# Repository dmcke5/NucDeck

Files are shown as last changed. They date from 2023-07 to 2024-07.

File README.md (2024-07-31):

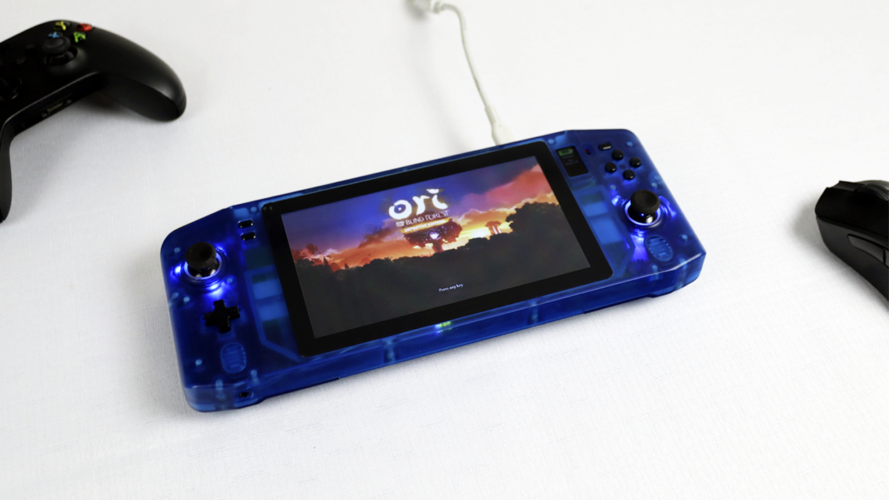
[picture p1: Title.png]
NucDeck


# NucDeck
The Open Source DIY Handheld Gaming PC!

Refer to "NucDeck Assembly Instructions.PDF" for mechanical assembly details. Information for the electronics will be added once the controller PCB's are complete.

There are two different versions of the housing, Standard and NoRGB. The NoRGB version has had
the RGB joystick surrounds removed to simplify printing. If you choose the NoRGB version you can leave all of the 
associated components off the PCB's to save on cost.

There are two different versions of the buttons, membrane and clicky. The Membrane buttons are shorter and are
designed to be used with silicone membranes. I've included files for molds to make the membranes. If you have a resin printer
I encourage you to give this a try as it improves the feel of the buttons dramatically. FDM printers will struggle to produce the accuracy required to make these parts. The clicky version is slightly taller and can be used without the membranes.

Total Cost of parts approximately: $311 USD

This is based on PCBway's pricing for the PCB's and is not including a NUC or any shipping charges. I've probably missed counting something so I would budget for a little more!

Here's a breakdown of the costs:
- Digikey parts: $55 USD
- PCB's (Set of 5 due to MOQ): $204 USD
- Aliexpress Parts: $52 USD

If you can organise a group of 5 people who want a set of PCB's, you will greatly reduce your total cost to build.

#### Project Status
- [x] 3D Files
- [x] Software: V1.0 ready for testing. Motion controls not yet implemented
- [x] PCBs: Complete

Watch the series on Youtube as I design, build and test parts of this project:
- [Episode 1](https://youtu.be/xVYYCx3Qt4Y)
- [Episode 2](https://youtu.be/nOXd3axX4fw)
- [Episode 3](https://youtu.be/yHMnScoKIOE)
- [Episode 4](https://youtu.be/rP_sMztufNs)
- [Episode 5](https://youtu.be/sQocfy4pwIQ)
- [Bonus Episode - Battery Life Testing](https://youtu.be/6FQKwnMxRxI)
- [Episode 6](https://youtu.be/mfuAvgmuT2s)
- [Episode 7](https://youtu.be/nFNw7_WkteA)
- [Episode 8](https://youtu.be/YYRD0Zlga5s)
- [Episode 9](https://youtu.be/t9Rao_BeIeM)

I've found links for all of the parts on Aliexpress since its probably the cheapest option and will ship worldwide.

## Parts List

#### Display

Any 1024x600 50 Pin RGB Panel with overall dimensions no greater than 164.9x100x3.3mm.
This is the 700nit IPS panel I ended up using: https://www.aliexpress.com/item/1005005315348504.html

#### Display Driver

Pick the "PCB800812V1" option:
https://www.aliexpress.com/item/1005004252996145.html

#### USB Touch Controller

Pick option "USB Controller":
https://www.aliexpress.com/item/32976239800.html

#### Capacitive Touch Panel

This is the seller I used, but anyone selling for the same model tablet (Pritom K7) should do:
https://www.aliexpress.com/item/1005002490383977.html

#### Joysticks

Joysticks are an Alps RKJX21224001. Here's a cheap seller on aliexpress:
https://www.aliexpress.com/item/1005005264696228.html
Joystick caps are Xbox One compatible.

#### Batteries

4x 605080 3000mah Lithium cells. Here's a cheap supplier on Aliexpress:
https://www.aliexpress.com/item/32990176071.html

#### Info Screen

0.96" IPS 80x160 ST7735 TFT Display

You need the one these guys refer to as "Spliced Type".
https://www.aliexpress.com/item/1005001598020071.html

#### Threaded Inserts

Measurments are: Thread x OD x Length

17x M2x3.2x4

10x M3x5x5

2x M3x5x4

https://www.aliexpress.com/item/1005003582355741.html

#### Standoffs

10x M2x6mm Male to Female Standoffs
https://www.aliexpress.com/item/4001271908929.html

#### Trigger Springs

--NOTE-- Ignore the wire thickness in the Assembly Drawing, it is incorrect. I will fix it when I next need to make changes. Correct thickness listed here.
These guys have a lot of different options, they are pretty cheap so I'd grab a few different wire thicknesses
and test them out to see what you like. You need about 2mm ID on the coil section, so look for an ID of at least double the wire
thickness greater than 2mm. I found 0.4mm to feel a bit too thin, and 0.7mm is about the limit of the trigger supports so 0.5-0.6mm is probably the sweet spot.
https://www.aliexpress.com/item/1005004968066601.html

#### Trigger Magnets

You'll never need fridge magnets again!
https://www.aliexpress.com/item/1005003794726533.html

#### RGB Lights

You'll need both RGB LED's and WS2811 IC's if you're adding RGB to your controller PCB's.
These are the LED's I used. Any alternative in the same sized package should be fine too, just be cautious of
differing pin configurations.
https://www.aliexpress.com/item/1005003719602946.html

WS2811 IC's:
https://www.aliexpress.com/item/32844615804.html

#### Screws

Here's a list of the screws required for assembly. This list is also in the assembly instructions. SCHS is just a standard allen key head screw. CSK is a countersunk head screw. Most bolt suppliers should have these, otherwise ebay or aliexpress is your friend.

12x M3x6mm SHCS
2x M2x16 CSK
9x M2x5 CSK
14x M2x4 SHCS

#### 4s Cell Balancer
https://www.aliexpress.com/item/1005005827876691.html

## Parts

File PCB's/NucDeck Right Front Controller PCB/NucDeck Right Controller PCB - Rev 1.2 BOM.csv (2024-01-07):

All parts available from Digikey unless otherwise specified
Ref | Qnty | Value/Part Number | Footprint | Supplier
A1,B1,X1,Y1,MENU1 | 5 | EVQ-Q2B02W | SW_EVQ-Q2B02W
C1, C2, C3, C4 | 4 | 0.1uF | Capacitor 0603_1608Metric
D1, D2, D3 | 3 | LED_BRGK | LED_SMD:LED_T36K3BGR-05D000121U1930 | https://www.aliexpress.com/item/1005003719602946.html
Display_Power1 | 1 | 532617002 | MOLEX_532617002
J1 | 1 | 5052781033 | Molex Easy On Connector:Molex 5052781033
J2 | 1 | 2-1734592-2 | CONN22_2-1734592-2
J3 | 1 | 5051100892 | CON_5051100892_MOL
J4 | 1 | USB4125-GF-A-0190 | USB4125-GF-A-0190
POWER1 | 1 | TL3330AF130QG | SW_TL3330AF130QG
R1 | 1 | TL1105VF160Q | SW_TL1105VF160Q
R2, R3, R5, R6, R8, R10 | 6 | R33 | Resistor 0603_1608Metric
R4, R7, R9 | 3 | 100R | Resistor 0603_1608Metric
R11 | 1 | 15ohm | Resistor 0603_1608Metric
R12 | 1 | 10ohm | Resistor 0603_1608Metric
R13 | 1 | 49.9K | Resistor 0603_1608Metric
R14 | 1 | 5.1K | Resistor 0603_1608Metric
Right_Speaker1 | 1 | 532617002 | MOLEX_532617002
Toggle_Switch1 | 1 | SW_SPDT | NKK Slide Switch:NKK SS12SBP2
U1, U2, U3 | 3 | WS2811 | SOP-8_3.9x4.9mm_P1.27mm | https://www.aliexpress.com/item/32844615804.html
U4 | 1 | HUSB238 | DFN-10-1EP_3x3mm_P0.5mm_EP1.7x2.5mm | https://www.aliexpress.com/item/1005005555514096.html
U5 | 1 | FQD11P06TM | TO-252-3_ONS
U6 | 1 | BAT54XV2T1G | SOD-523_0P9X1P3_ONS
U7 | 1 | VO1400AEFTR | SO-4_VO_VIS

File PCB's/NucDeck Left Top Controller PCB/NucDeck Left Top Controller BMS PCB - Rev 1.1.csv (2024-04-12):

Qty | Reference(s) | Value
2 | C1, C2 | 47nF
1 | C3 | 4.7uF
9 | C4, C5, C6, C12, C13, C15, C16, C17, C18 | 10uF
7 | C7, C10, C11, C14, C21, C24, C31 | 0.1uF
1 | C8 | 1nF
1 | C9 | 2.2uF
2 | C19, C20 | 10uF
2 | C25, C26 | 1uF
1 | C27 | .47uF
1 | C28 | .1uF
1 | D1 | LED
1 | J1 | 527450697
1 | J2 | Molex 5052781033
1 | J3 | S5B-EH
1 | L1 | SPM6530T-2R2M
1 | R1 | 2.2K
1 | R2 | 27k
2 | R3, R13 | 100k
1 | R4 | 127k
1 | R5 | 2ohm
1 | R6 | 30.31K
1 | R7 | 5.24K
1 | R8 | 100ohm
1 | R12 | PCS2512DR0100ET
1 | R14 | 11.1k
1 | Thermistor | 103AT-5-1P-FT
1 | U1 | MAX17261METD+
1 | U2 | BQ25792RQMR
1 | U3 | DRV5053OAQDBZR
1 | U4 | SMBJ24CA
1 | U6 | NCP718xSN330

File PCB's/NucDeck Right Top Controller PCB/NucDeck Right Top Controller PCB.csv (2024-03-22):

All parts available from digikey unless otherwise specified
Qty | Reference(s) | Value | Footprint
6 | C1, C2, C3, C4, C5, C6 | 0.1uF | Capacitor 0603_1608Metric
1 | J1 | 527450697 | CON_527450697_MOL
1 | J2 | 2-1734592-2 | CONN22_2-1734592-2
1 | U1 | Pico | Raspberry Pi Pico
1 | U3 | DRV5053OAQDBZR | DBZ0003A_N

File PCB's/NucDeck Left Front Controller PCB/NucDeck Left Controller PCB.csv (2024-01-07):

All parts available from Digikey unless otherwise specified
Qty | Reference(s) | Value/Part Number | Footprint | Supplier
1 | C1 | 4.7uF | Capacitor 0603_1608Metric
8 | C2, C3, C6, C7, C8, C15, C16, C17 | 0.1uF | Capacitor 0603_1608Metric
2 | C4, C5 | 22pF | Capacitor 0603_1608Metric
3 | D1, D2, D3 | LED_BRGK | LED_T36K3BGR-05D000121U1930 | https://www.aliexpress.com/item/1005003719602946.html
6 | DN1, LEFT1, RIGHT1, Select1, Start1, UP1 | EVQ-Q2B02W | SW_EVQ-Q2B02W
1 | J1 | SJ-43516-SMT-TR | CUI_SJ-43516-SMT
2 | J2, J4 | 5052781033 | Molex 5052781033
1 | J3 | 532617002 | MOLEX_532617002
1 | L1 | TL1105VF160Q | SW_TL1105VF160Q
1 | R1 | 1K | Resistor 0603_1608Metric
3 | R2, R7, R10 | 100R | Resistor 0603_1608Metric
5 | R3, R4, R5, R6, R8 | R33 | Resistor 0603_1608Metric
1 | U1 | ATmega328P-A | TQFP-32_7x7mm_P0.8mm
3 | U2, U3, U4 | WS2811 | SOP-8_3.9x4.9mm_P1.27mm | https://www.aliexpress.com/item/32844615804.html
2 | Vol+1, Vol-1 | TL3330AF130QG | SW_TL3330AF130QG
1 | Y1 | 16 MHZ | Crystal_SMD_5032-4Pin_5.0x3.2mm

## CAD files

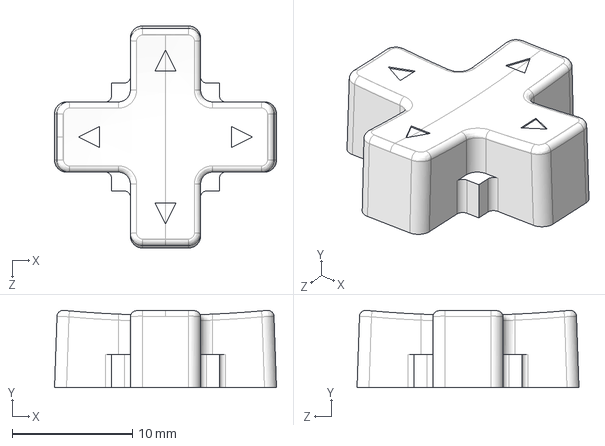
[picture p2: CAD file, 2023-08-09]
Buttons - STEP/Clicky Buttons - STEP/NUCDeck D-Pad - Clicky.STEP
18.5 x 6.42 x 18.5 mm

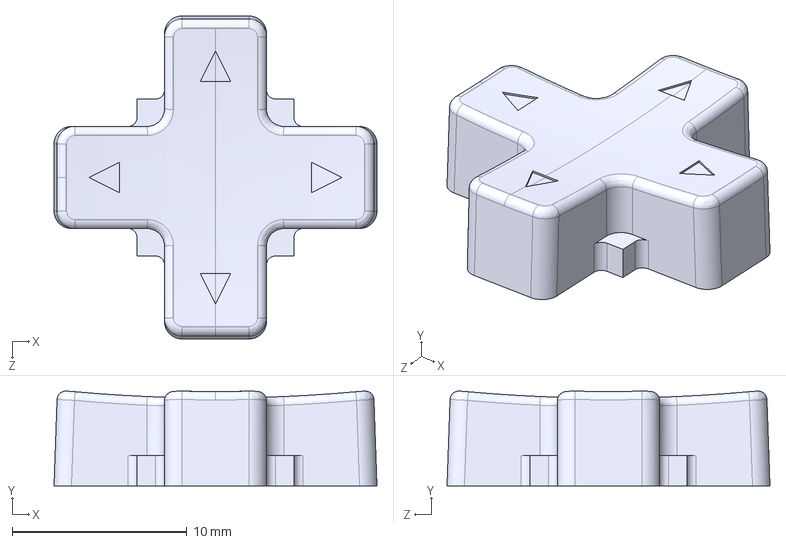
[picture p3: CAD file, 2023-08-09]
Buttons - STEP/Membrane Buttons - STEP/D-Pad - Standard.STEP
18.5 x 5.43 x 18.5 mm

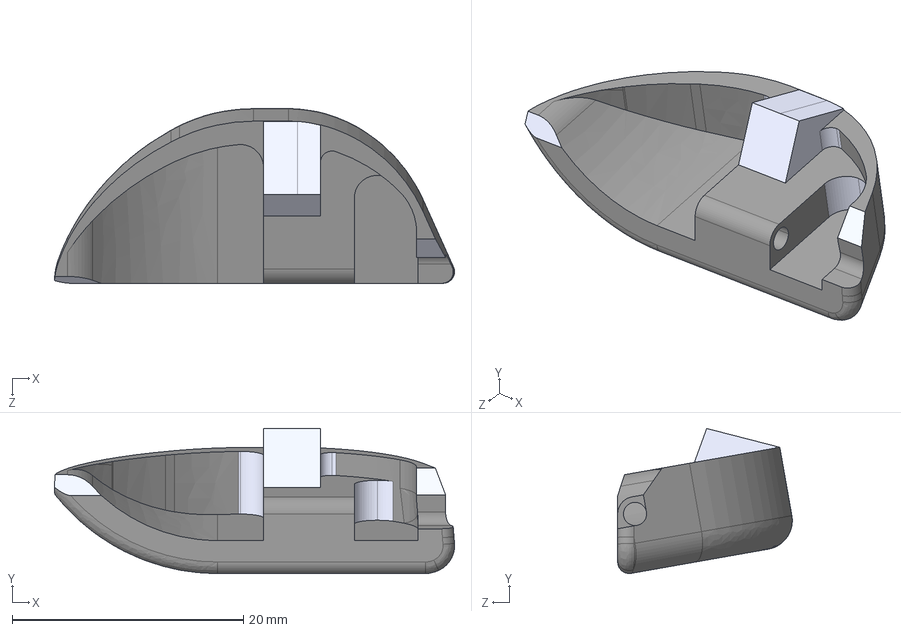
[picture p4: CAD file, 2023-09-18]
Buttons - STEP/Trigger Button Right.STEP
34.6 x 12.5 x 15.1 mm

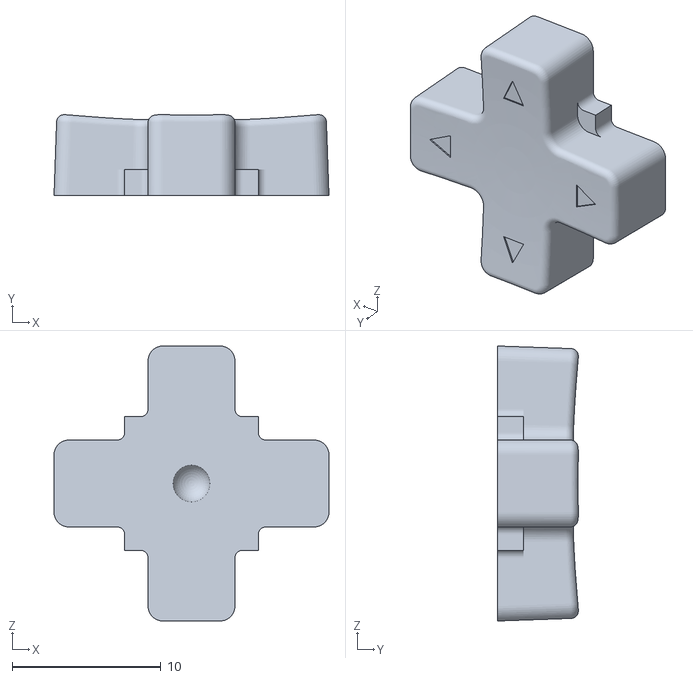
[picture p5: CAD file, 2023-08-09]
Buttons - STL/Membrane Buttons - STL/NUCDeck D-Pad - Standard.STL
18.5 x 5.43 x 18.5

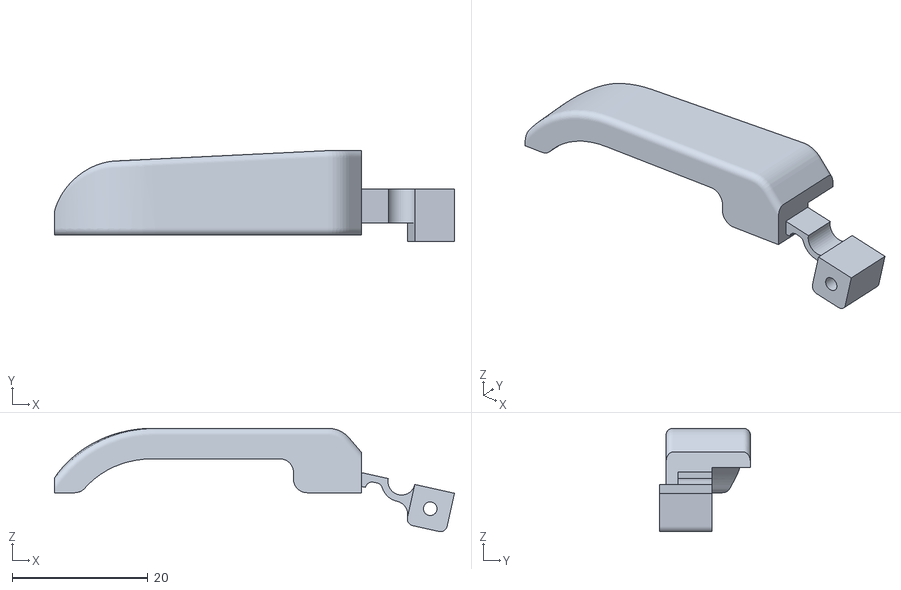
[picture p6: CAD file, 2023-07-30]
Buttons - STL/Right Shoulder Button - Printable Version.STL
59.0 x 13.4 x 15.2

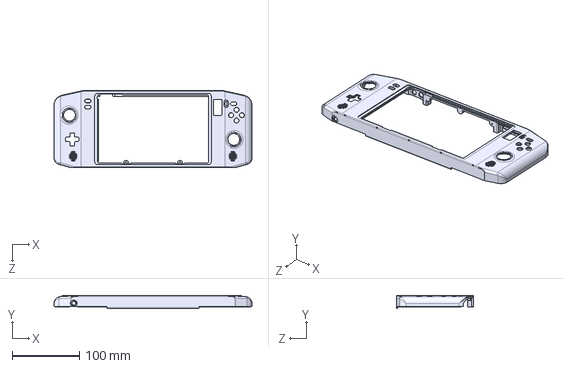
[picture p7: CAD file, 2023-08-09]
Housing - STEP/Housing Front - No RGB.STEP
294.0 x 19.0 x 115.0 mm

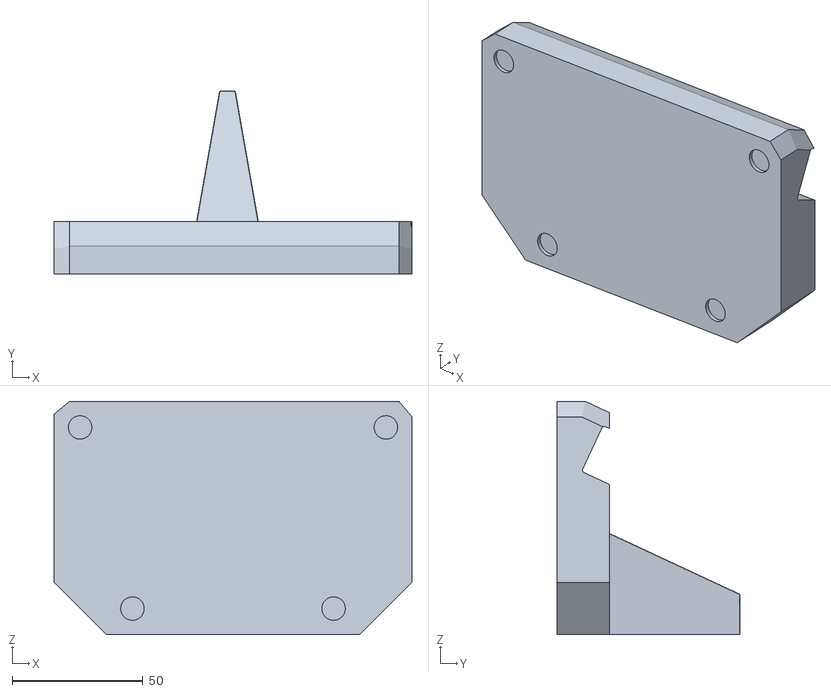
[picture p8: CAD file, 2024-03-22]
NucDeck Desktop Stand.STL
137.0 x 70.0 x 89.3

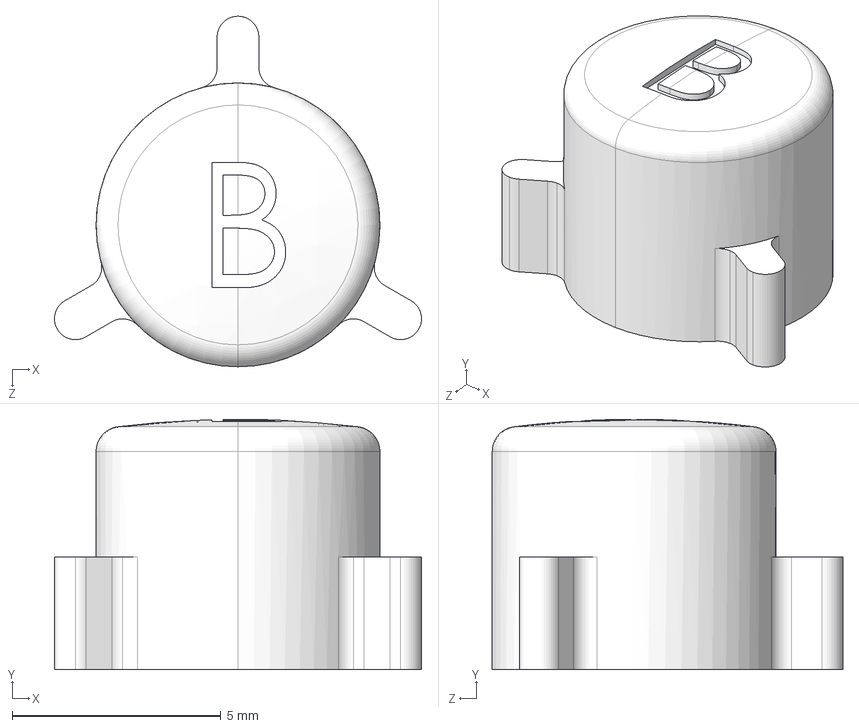
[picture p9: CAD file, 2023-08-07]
Buttons - STEP/Clicky Buttons - STEP/Action Button B - Clicky.STEP
8.79 x 6.00 x 8.40 mm

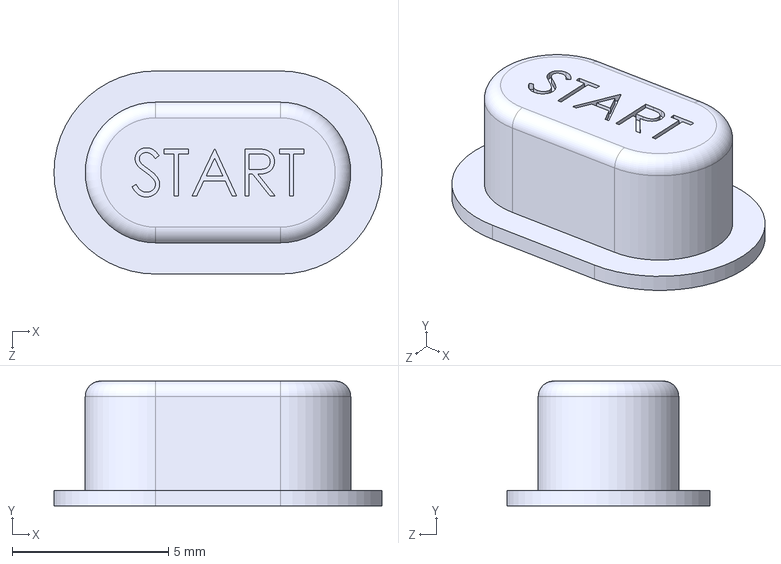
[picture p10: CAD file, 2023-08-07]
Buttons - STEP/Membrane Buttons - STEP/Start Button - Standard.STEP
10.5 x 4.00 x 6.50 mm

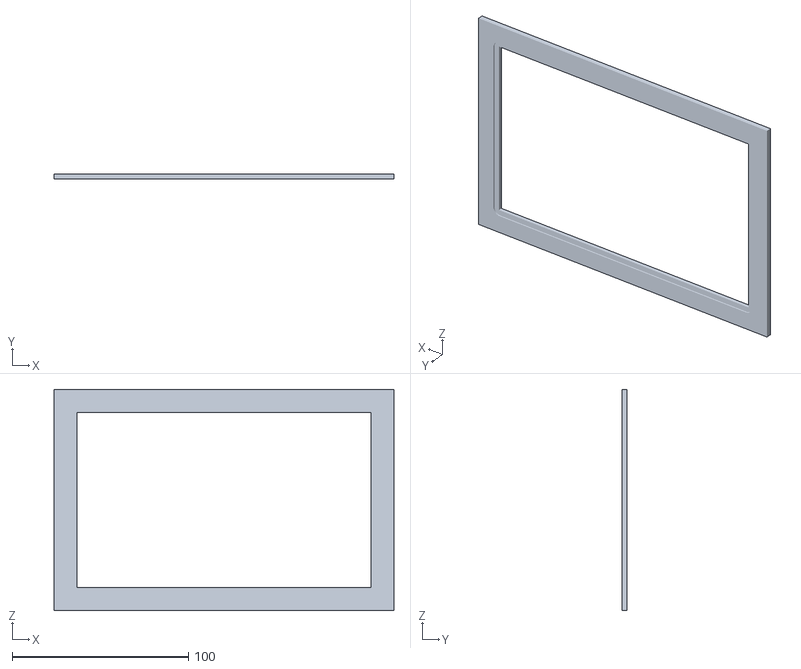
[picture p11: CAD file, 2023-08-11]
TouchScreen Scale Test.STL
193.0 x 3.00 x 125.6

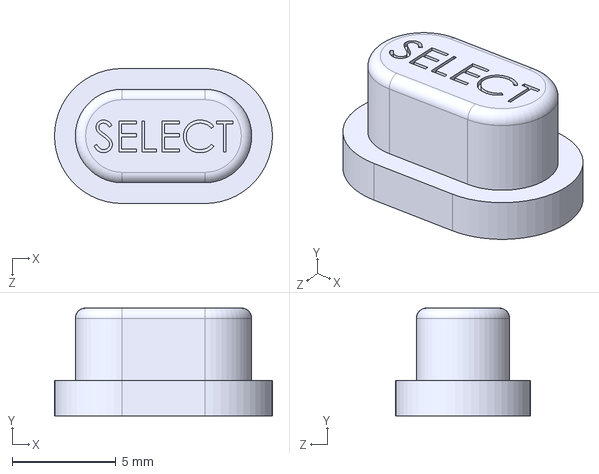
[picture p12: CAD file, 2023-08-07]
Buttons - STEP/Clicky Buttons - STEP/Select Button - Clicky.STEP
10.5 x 5.20 x 6.50 mm

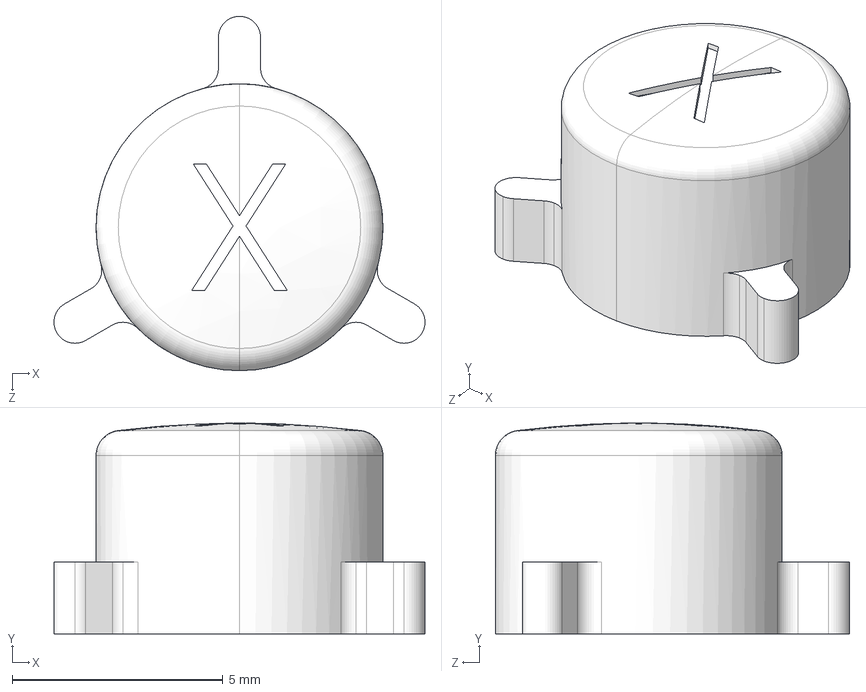
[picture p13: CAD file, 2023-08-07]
Buttons - STEP/Membrane Buttons - STEP/Action Button X - Standard.STEP
8.79 x 5.00 x 8.40 mm

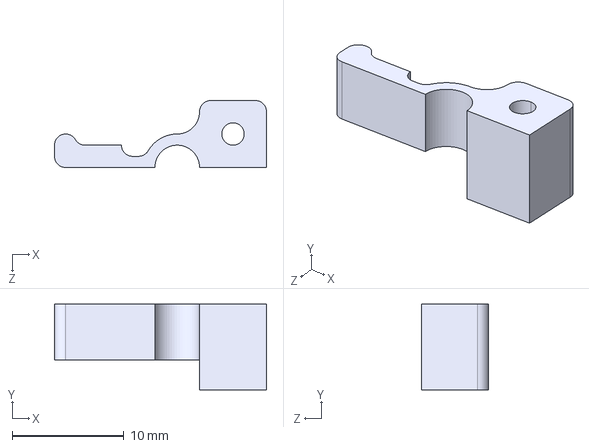
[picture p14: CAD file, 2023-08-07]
Buttons - STEP/Shoulder Spring - Right.STEP
19.0 x 7.70 x 6.00 mm

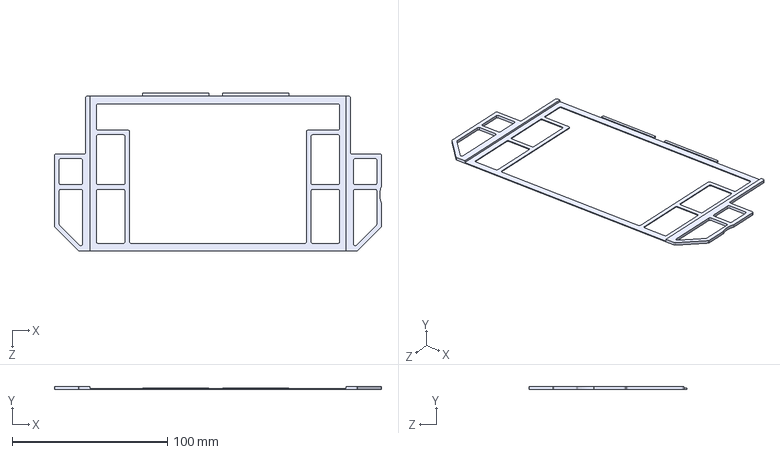
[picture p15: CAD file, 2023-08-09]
Housing - STEP/LCD Retainer.STEP
210.9 x 1.90 x 102.0 mm

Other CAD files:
Buttons - STEP/Trigger Button Left.STEP
Buttons - STL/Left Shoulder Button - Printable Version.STL
Housing - STEP/Housing Front.STEP
Buttons - STEP/Clicky Buttons - STEP/Start Button - Clicky.STEP
Buttons - STEP/+ Volume Button.STEP
Buttons - STEP/- Volume Button.STEP
Buttons - STEP/Clicky Buttons - STEP/Action Button A - Clicky.STEP
Buttons - STEP/Clicky Buttons - STEP/Action Button X - Clicky.STEP
Buttons - STEP/Clicky Buttons - STEP/Action Button Y - Clicky.STEP
Buttons - STEP/Clicky Buttons - STEP/Menu Button - Clicky.STEP
Buttons - STEP/Controller Mode Toggle.STEP
Buttons - STEP/Membrane Buttons - STEP/Action Button A - Standard.STEP
Buttons - STEP/Membrane Buttons - STEP/Action Button B - Standard.STEP
Buttons - STEP/Membrane Buttons - STEP/Action Button Y - Standard.STEP
Buttons - STEP/Membrane Buttons - STEP/Menu Button - Standard.STEP
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

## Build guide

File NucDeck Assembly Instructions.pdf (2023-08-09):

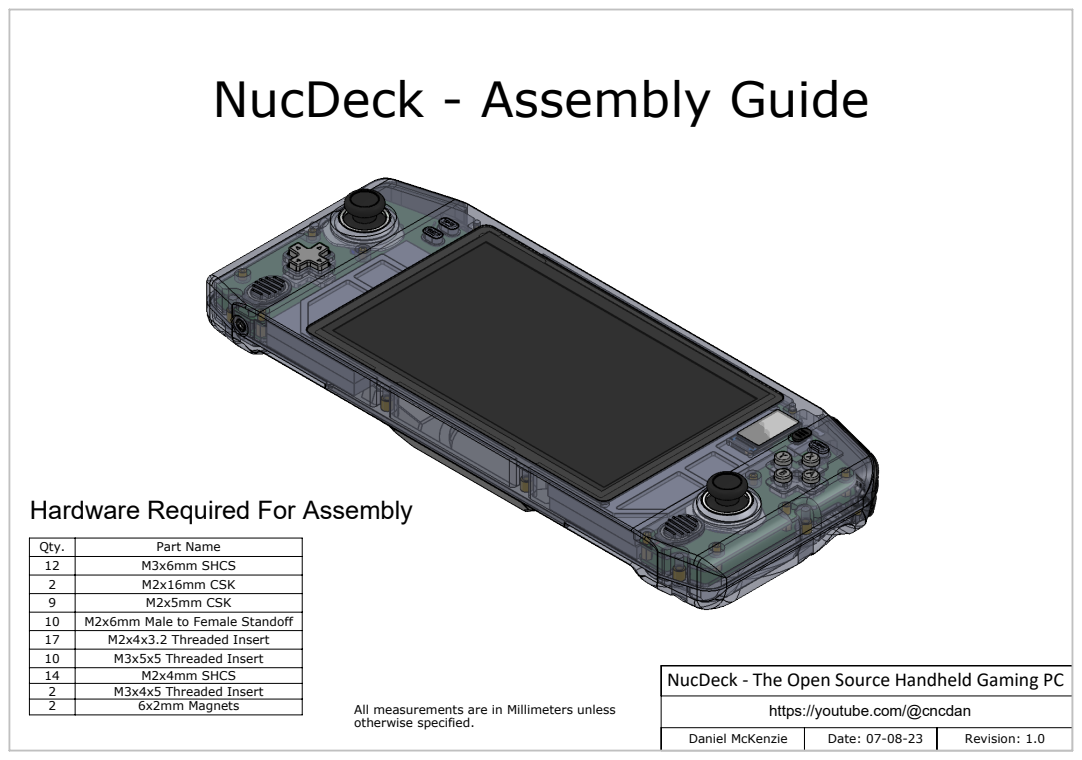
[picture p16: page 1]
M2x4mm SHCS; Daniel McKenzie; Date: 07-08-23; Revision: 1.0

NucDeck - Assembly Guide

Hardware Required For Assembly

Qty. | Part Name
12 | M3x6mm SHCS
2 | M2x16mm CSK
9 | M2x5mm CSK
10 | M2x6mm Male to Female Standoff
17 | M2x4x3.2 Threaded Insert
10 | M3x5x5 Threaded Insert

NucDeck - The Open Source Handheld Gaming PC

2 | M3x4x5 Threaded Insert
2 | 6x2mm Magnets

All measurements are in Millimeters unless
otherwise specified.

https://youtube.com/@cncdan

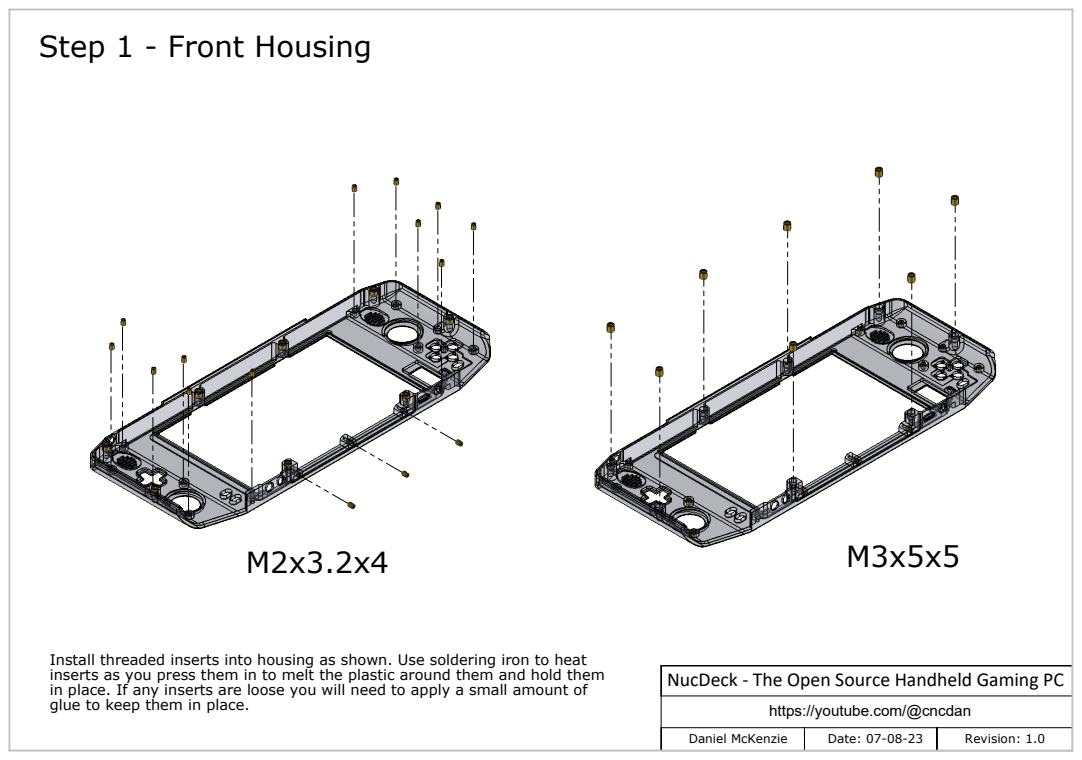
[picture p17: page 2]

Step 1 - Front Housing

Install threaded inserts into housing as shown. Use soldering iron to heat
inserts as you press them in to melt the plastic around them and hold them
in place. If any inserts are loose you will need to apply a small amount of
glue to keep them in place.

NucDeck - The Open Source Handheld Gaming PC

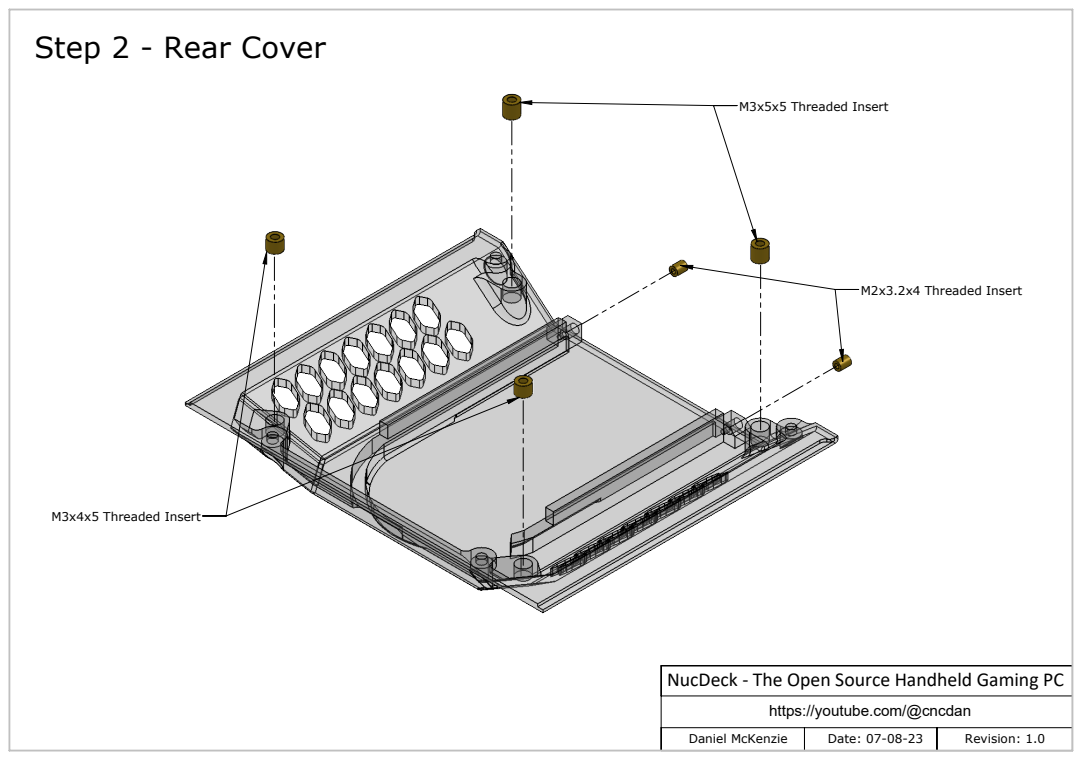
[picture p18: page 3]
M3x5x5 Threaded Insert; M3x4x5 Threaded Insert; M2x3.2x4 Threaded Insert

Step 2 - Rear Cover

NucDeck - The Open Source Handheld Gaming PC

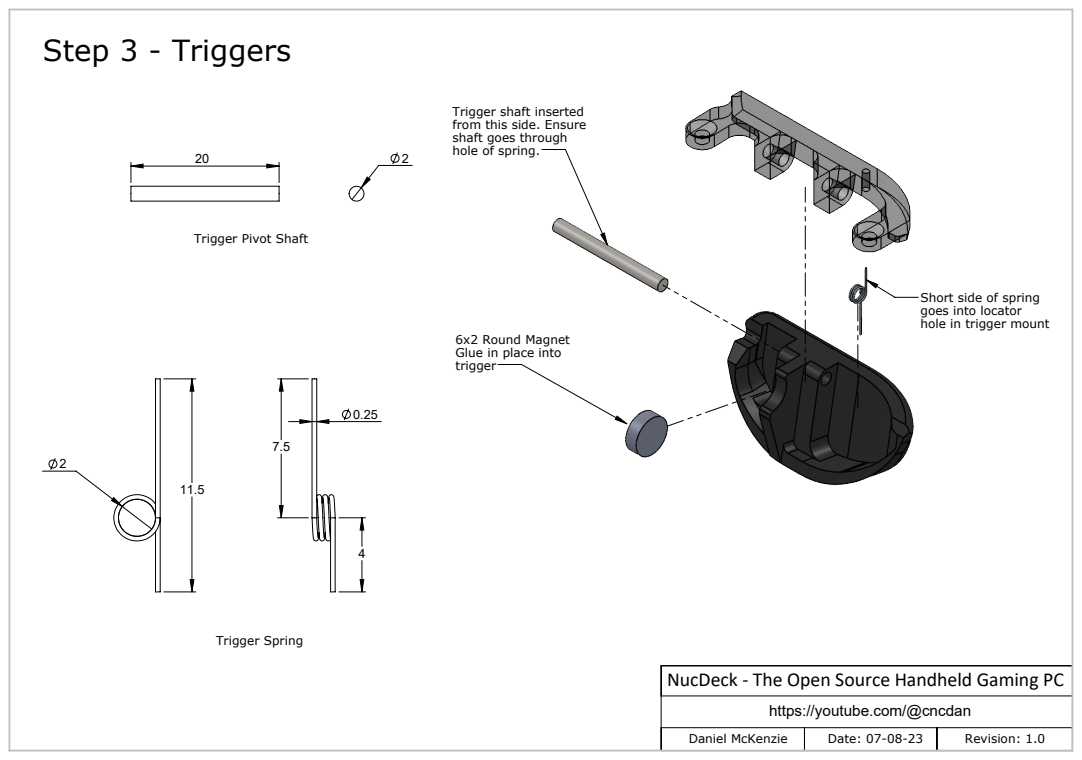
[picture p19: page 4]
Step 3 - Triggers; Trigger Spring

Trigger shaft inserted
from this side. Ensure
shaft goes through
hole of spring.

Trigger Pivot Shaft

Short side of spring
goes into locator
hole in trigger mount

6x2 Round Magnet
Glue in place into
trigger

NucDeck - The Open Source Handheld Gaming PC

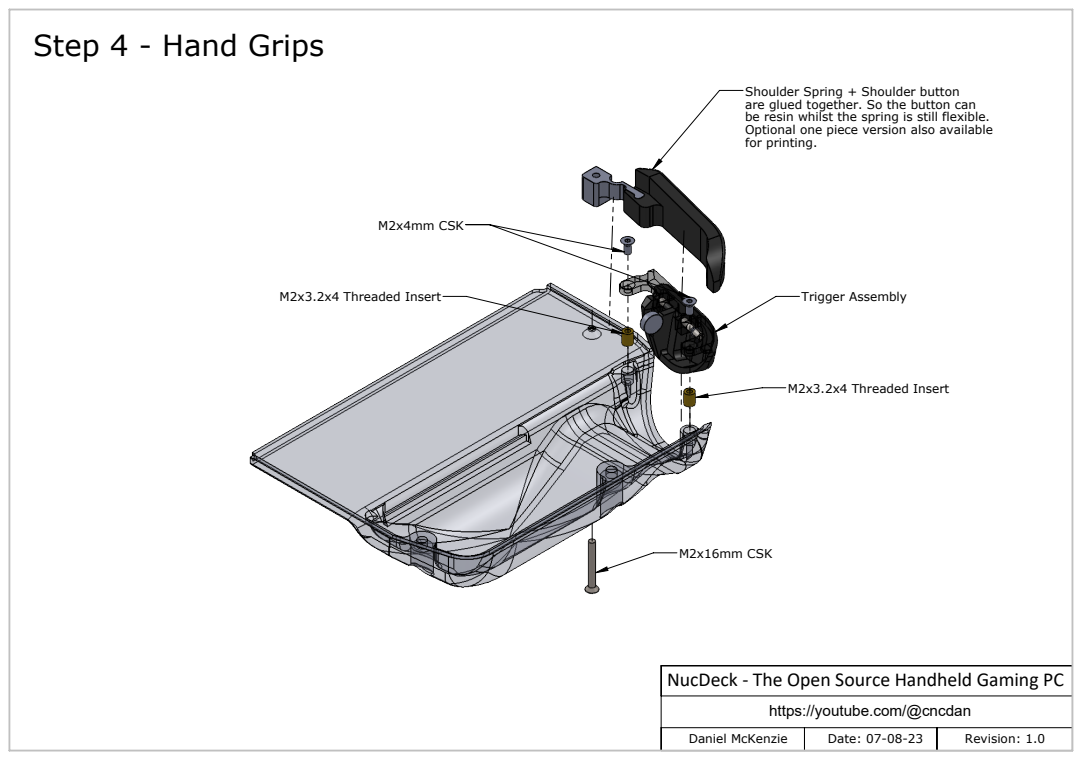
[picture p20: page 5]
Trigger Assembly; M2x3.2x4 Threaded Insert; M2x16mm CSK; M2x4mm CSK

Step 4 - Hand Grips

Shoulder Spring + Shoulder button
are glued together. So the button can
be resin whilst the spring is still flexible.
Optional one piece version also available
for printing.

NucDeck - The Open Source Handheld Gaming PC

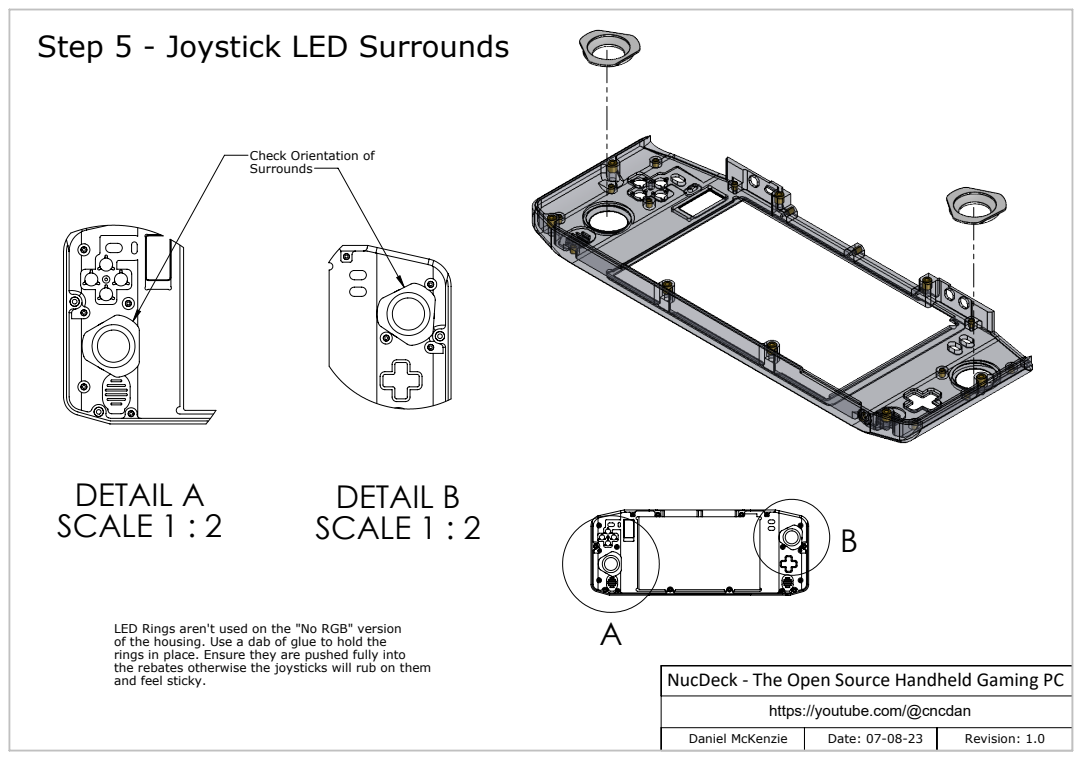
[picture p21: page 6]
DETAIL A SCALE 1 : 2; DETAIL B SCALE 1 : 2

Step 5 - Joystick LED Surrounds

Check Orientation of
Surrounds

LED Rings aren't used on the "No RGB" version
of the housing. Use a dab of glue to hold the
rings in place. Ensure they are pushed fully into
the rebates otherwise the joysticks will rub on them
and feel sticky.

NucDeck - The Open Source Handheld Gaming PC

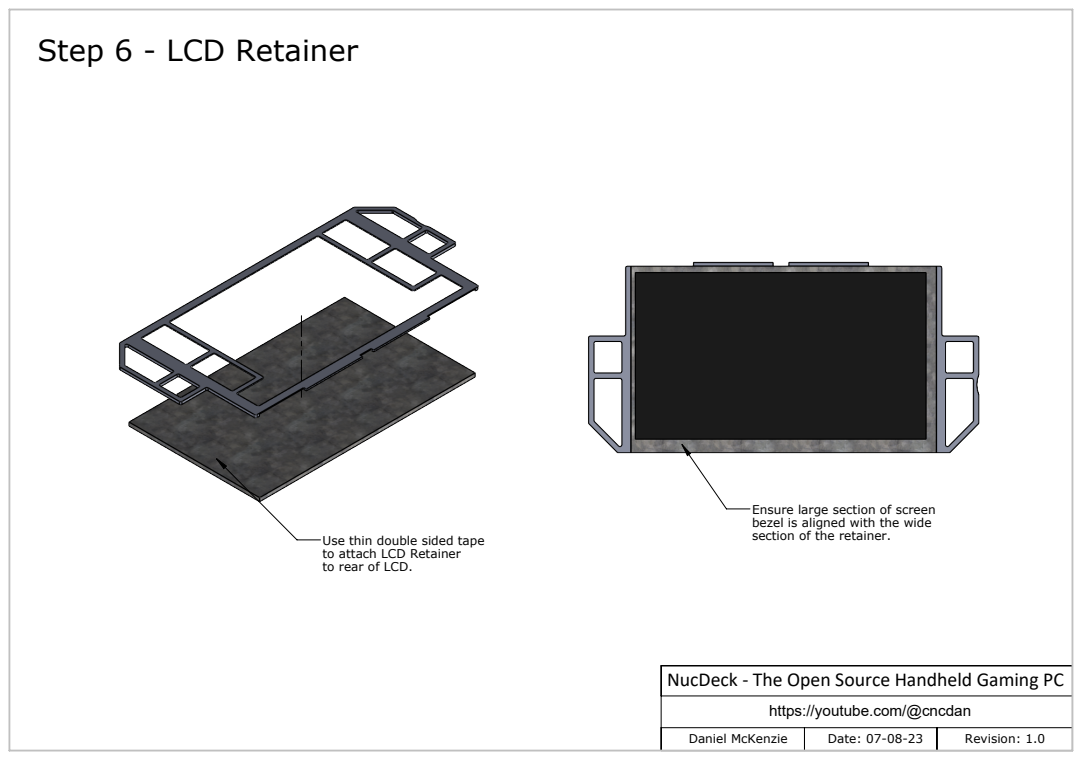
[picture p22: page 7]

Step 6 - LCD Retainer

Ensure large section of screen
bezel is aligned with the wide
section of the retainer.

Use thin double sided tape
to attach LCD Retainer
to rear of LCD.

NucDeck - The Open Source Handheld Gaming PC

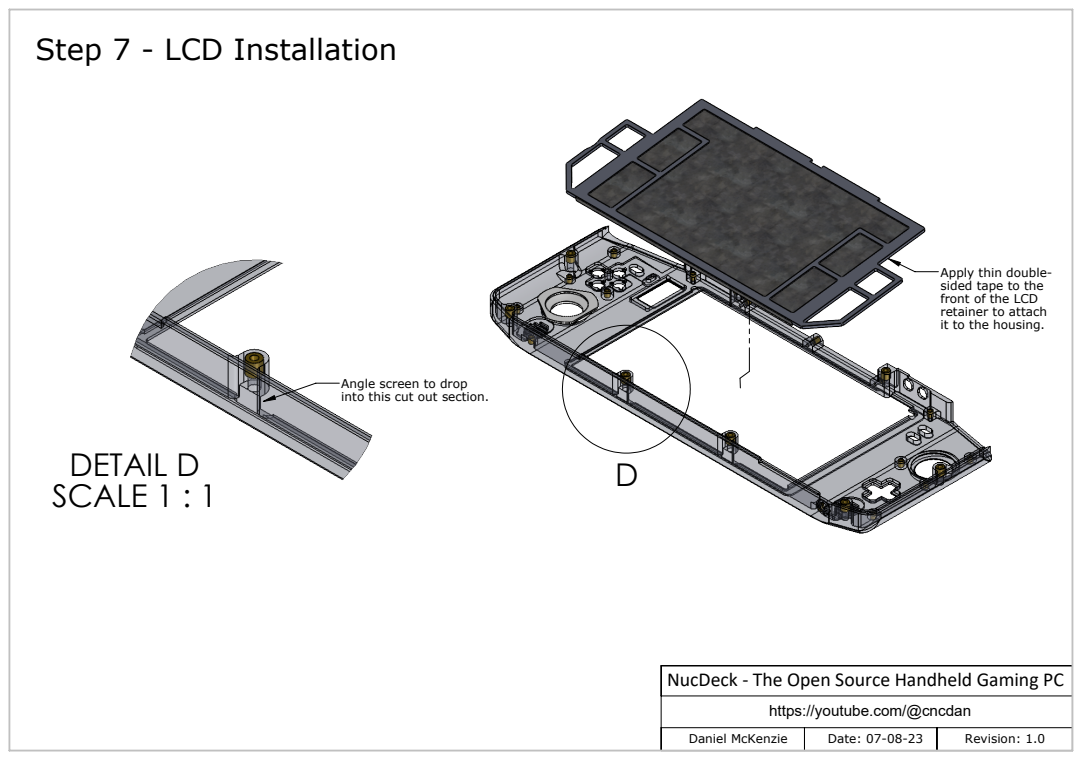
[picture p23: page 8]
DETAIL D SCALE 1 : 1

Step 7 - LCD Installation

Apply thin double-
sided tape to the
front of the LCD
retainer to attach
it to the housing.

Angle screen to drop
into this cut out section.

NucDeck - The Open Source Handheld Gaming PC

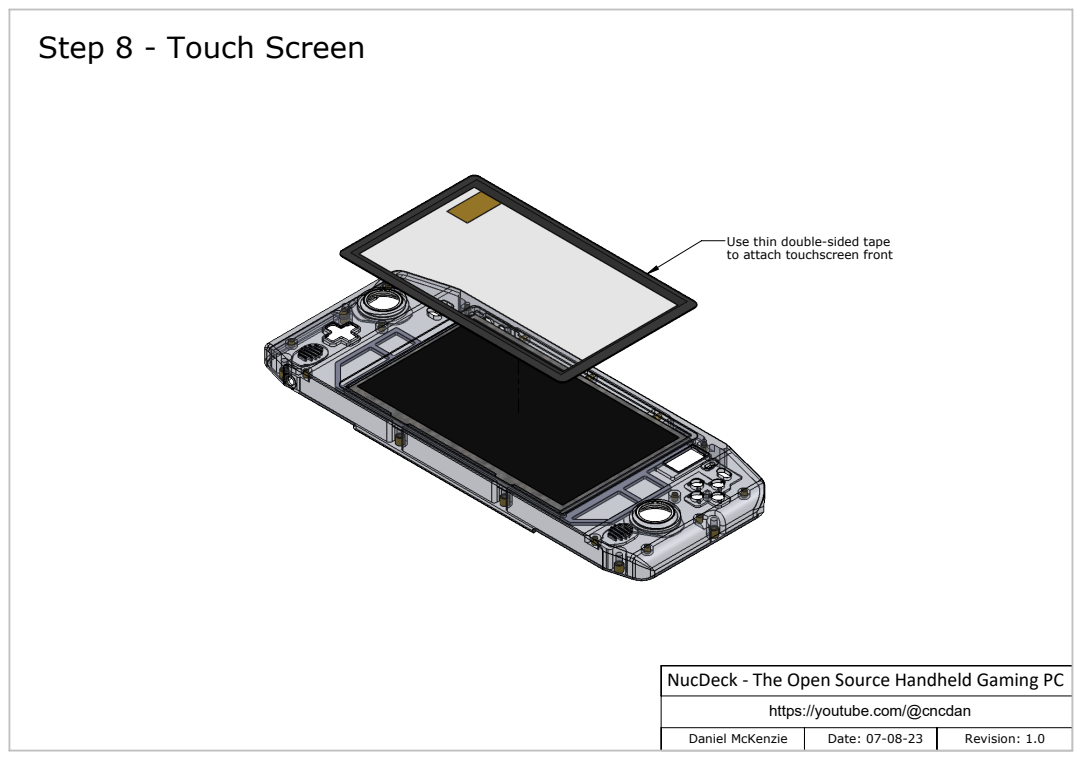
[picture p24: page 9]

Step 8 - Touch Screen

Use thin double-sided tape
to attach touchscreen front

NucDeck - The Open Source Handheld Gaming PC

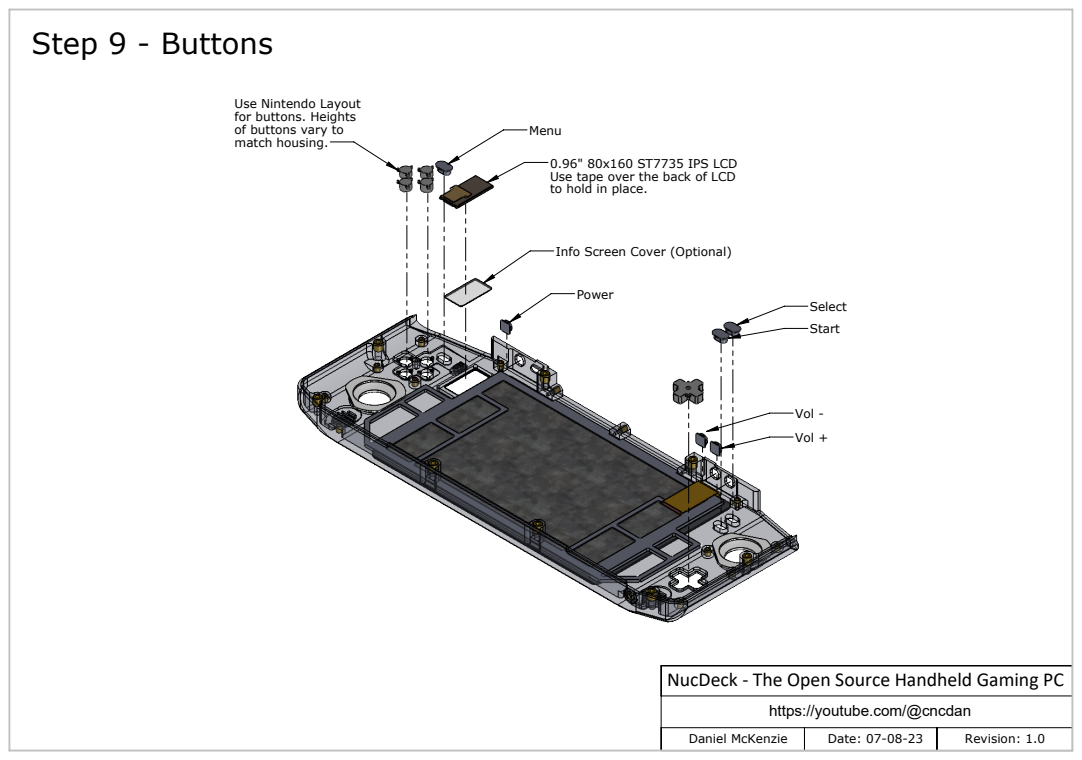
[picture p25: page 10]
Vol +; Vol -; Step 9 - Buttons

Use Nintendo Layout
for buttons. Heights
of buttons vary to
match housing.

0.96" 80x160 ST7735 IPS LCD
Use tape over the back of LCD
to hold in place.

Info Screen Cover (Optional)

NucDeck - The Open Source Handheld Gaming PC

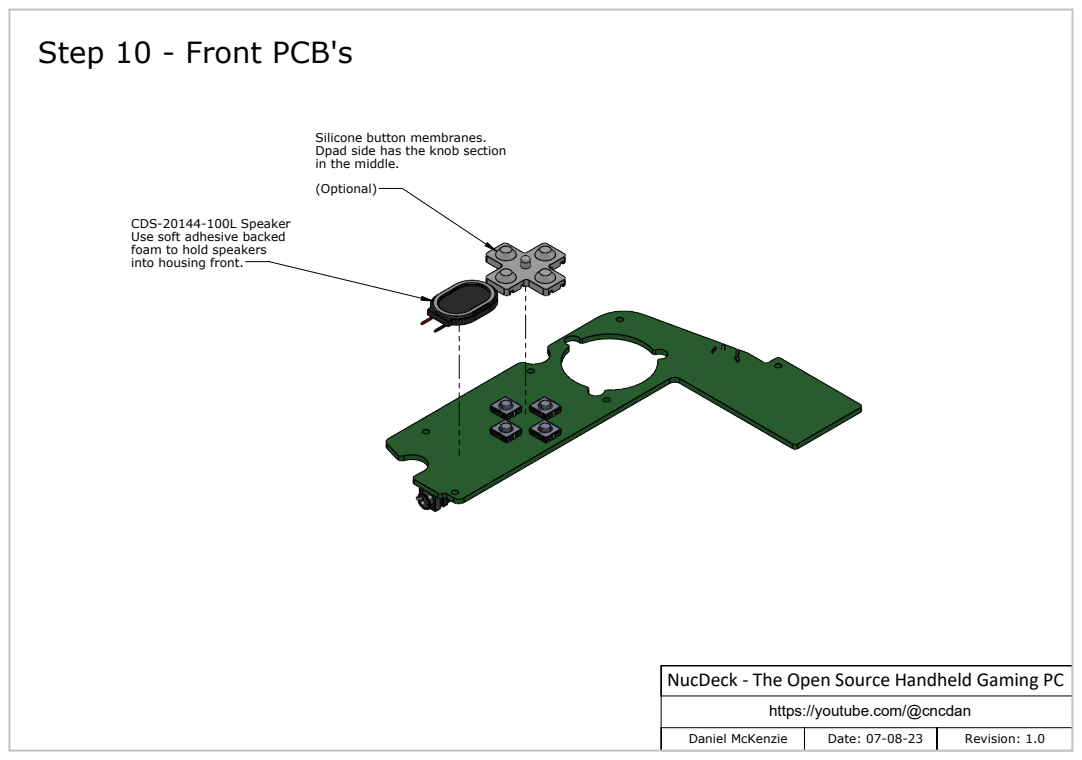
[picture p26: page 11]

Step 10 - Front PCB's

Silicone button membranes.
Dpad side has the knob section
in the middle.
(Optional)

CDS-20144-100L Speaker
Use soft adhesive backed
foam to hold speakers
into housing front.

NucDeck - The Open Source Handheld Gaming PC

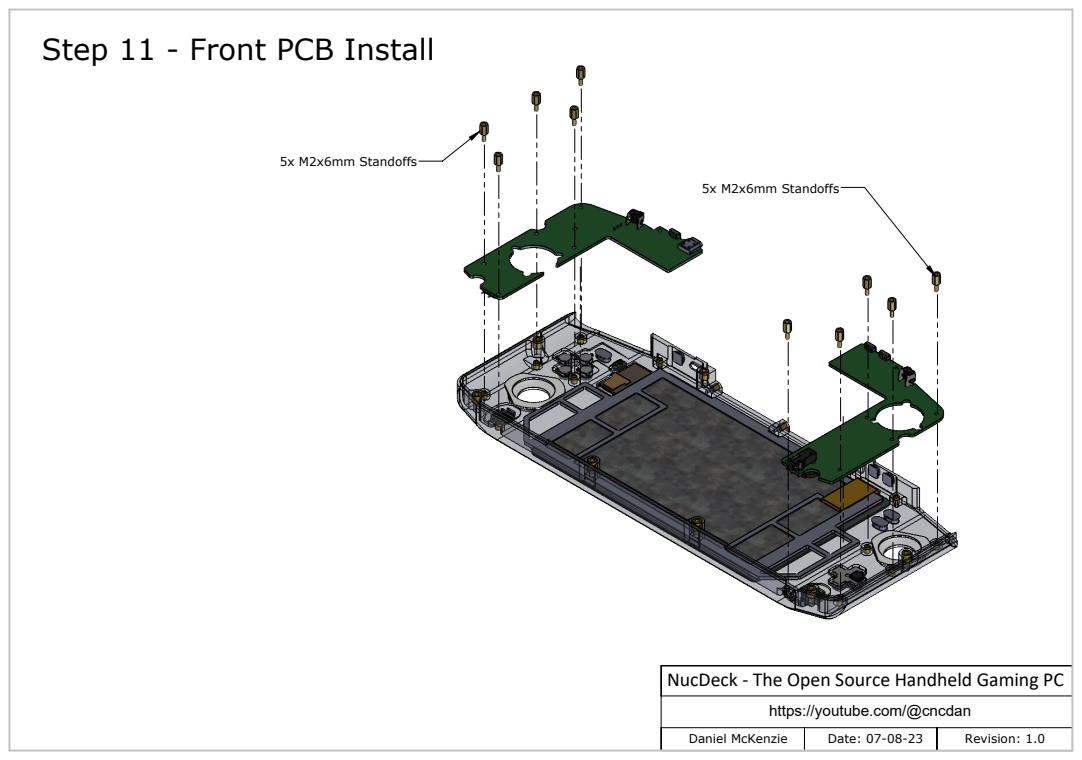
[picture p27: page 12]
5x M2x6mm Standoffs

Step 11 - Front PCB Install

NucDeck - The Open Source Handheld Gaming PC

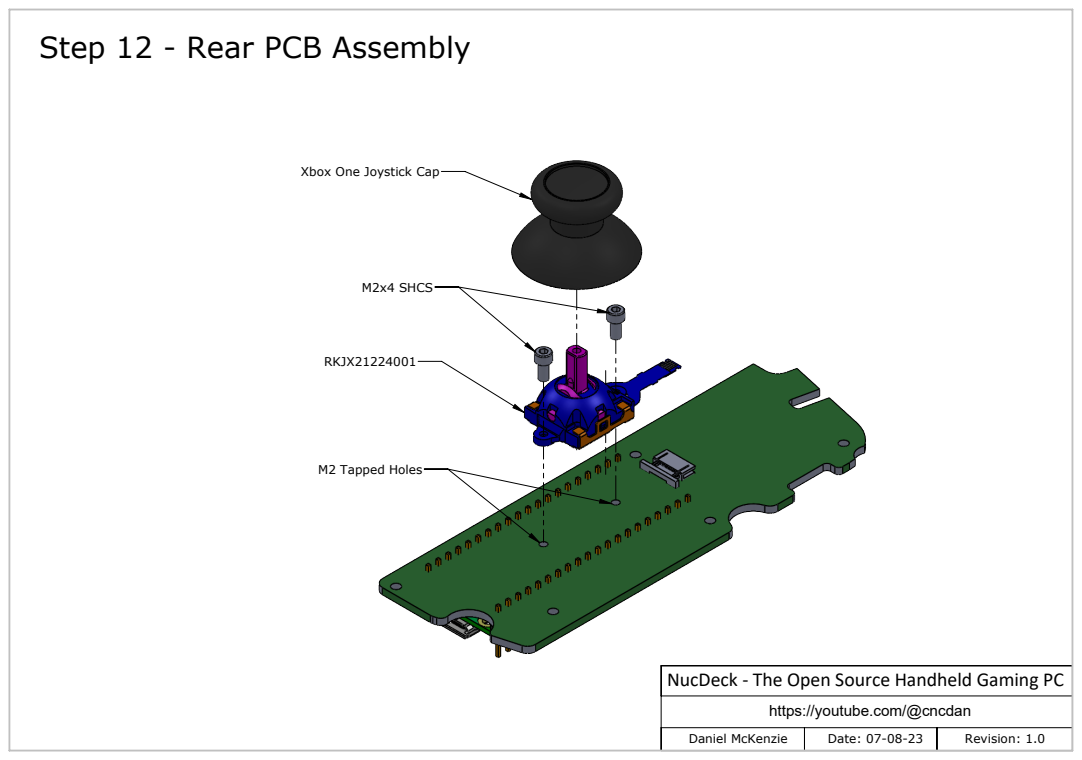
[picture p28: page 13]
M2x4 SHCS; M2 Tapped Holes

Step 12 - Rear PCB Assembly

Xbox One Joystick Cap

NucDeck - The Open Source Handheld Gaming PC

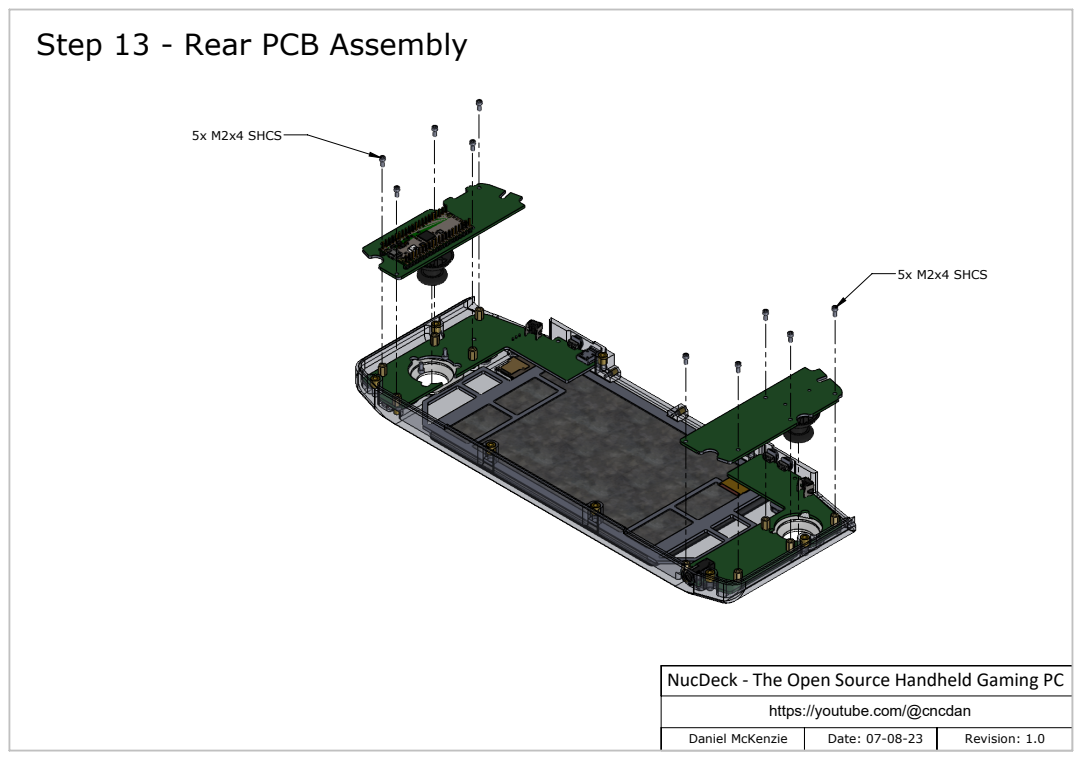
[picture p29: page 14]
5x M2x4 SHCS

Step 13 - Rear PCB Assembly

NucDeck - The Open Source Handheld Gaming PC

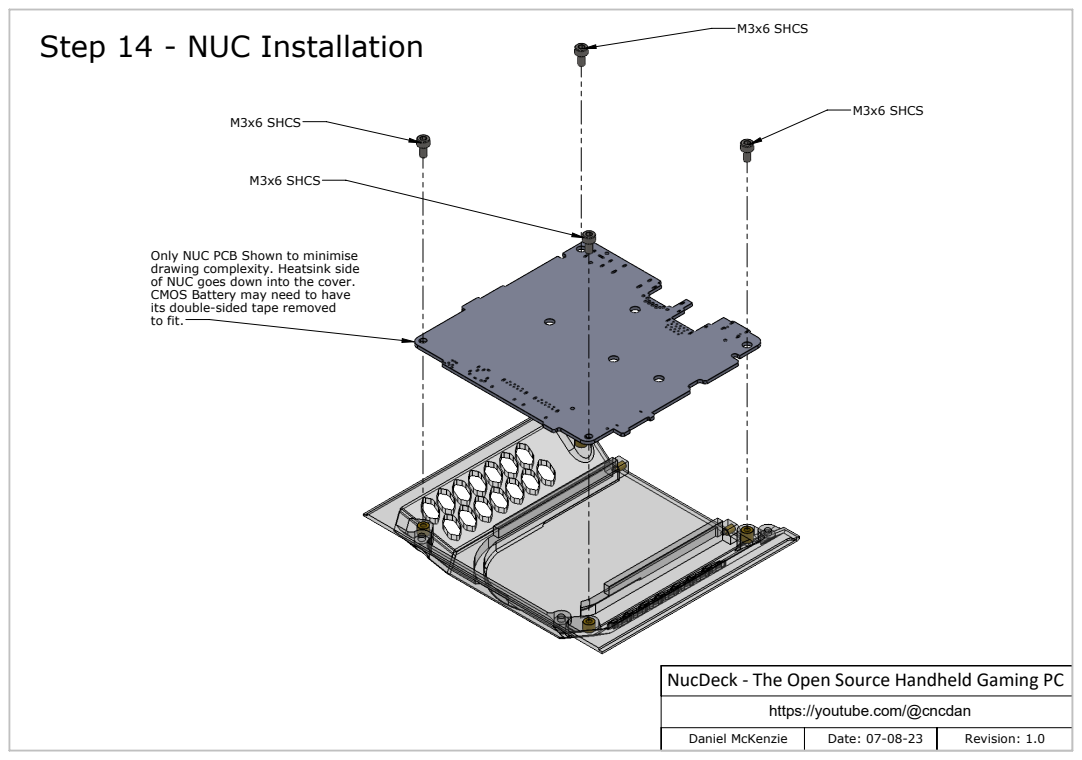
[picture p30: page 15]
M3x6 SHCS

Step 14 - NUC Installation

Only NUC PCB Shown to minimise
drawing complexity. Heatsink side
of NUC goes down into the cover.
CMOS Battery may need to have
its double-sided tape removed
to fit.

NucDeck - The Open Source Handheld Gaming PC

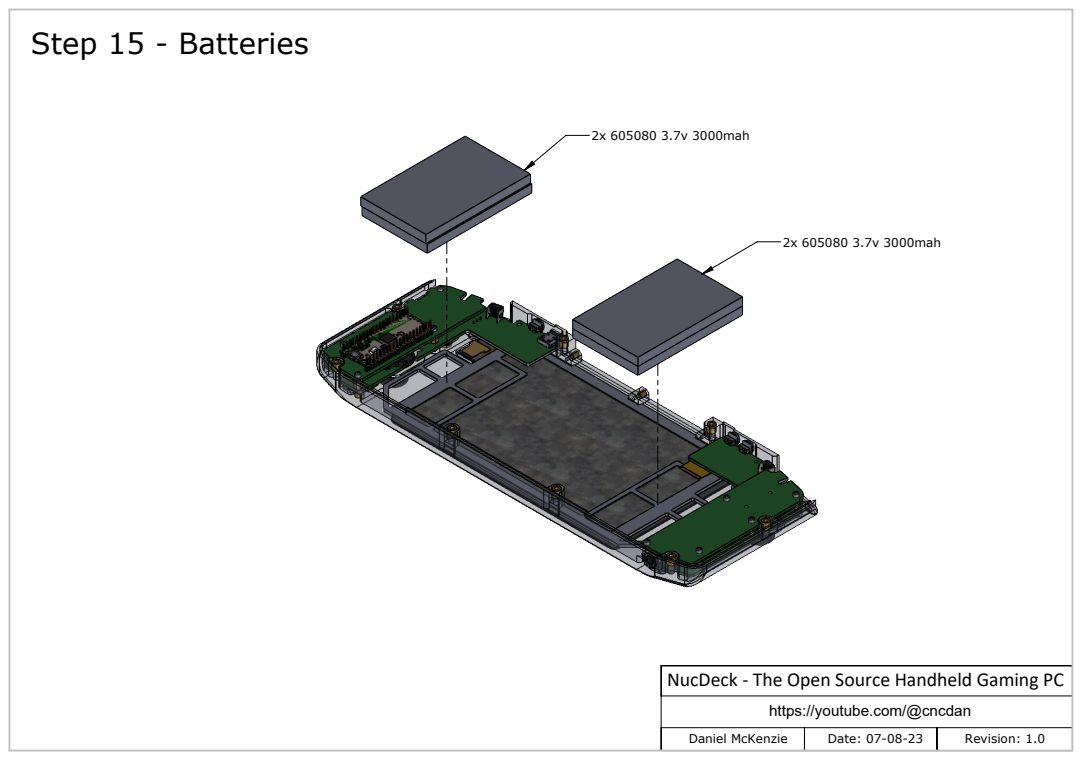
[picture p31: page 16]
2x 605080 3.7v 3000mah; Step 15 - Batteries

NucDeck - The Open Source Handheld Gaming PC

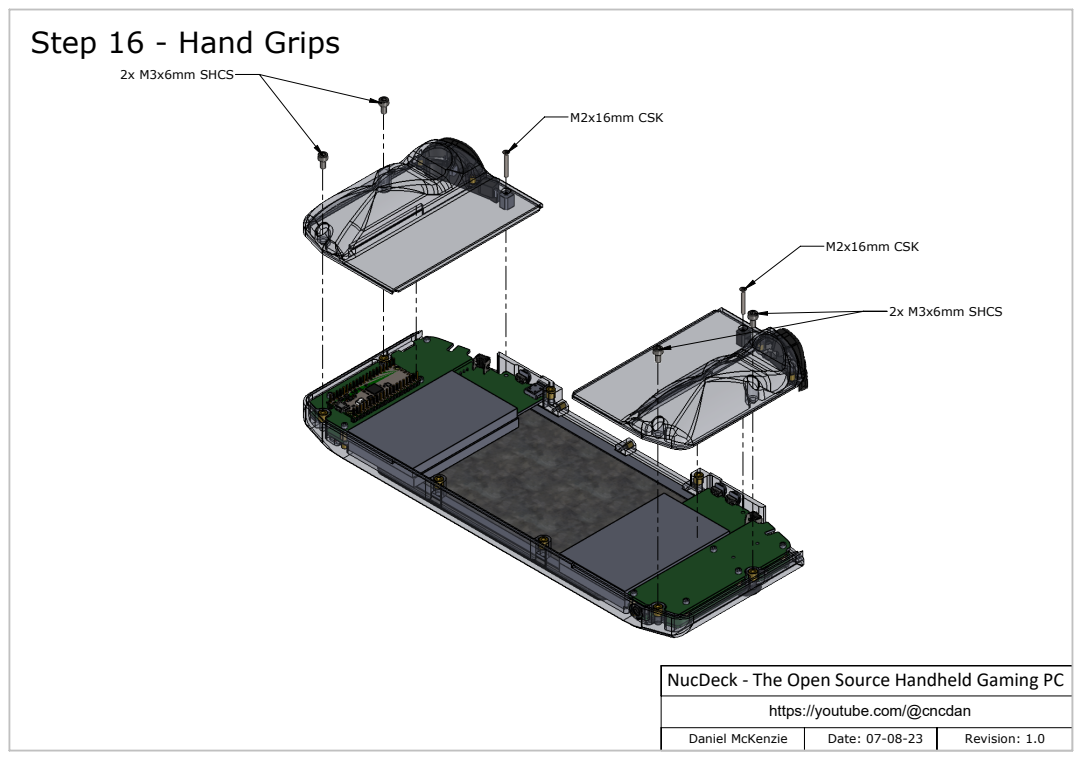
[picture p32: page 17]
2x M3x6mm SHCS; M2x16mm CSK

Step 16 - Hand Grips

NucDeck - The Open Source Handheld Gaming PC

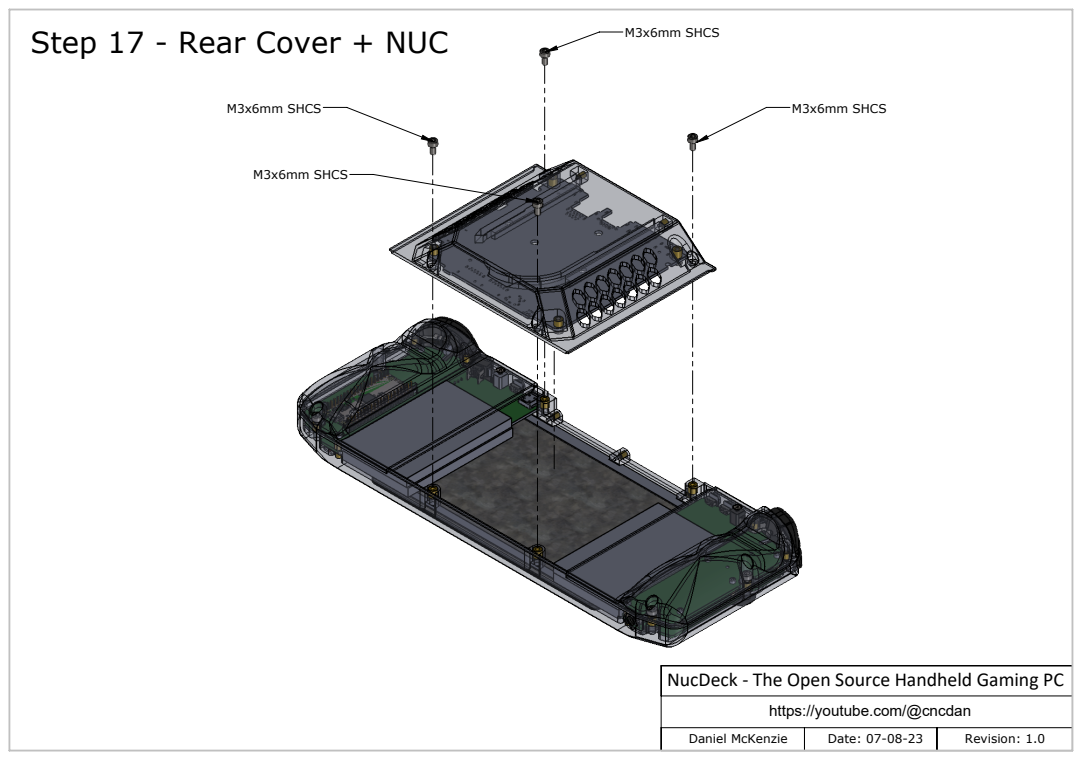
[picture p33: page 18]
M3x6mm SHCS

Step 17 - Rear Cover + NUC

NucDeck - The Open Source Handheld Gaming PC

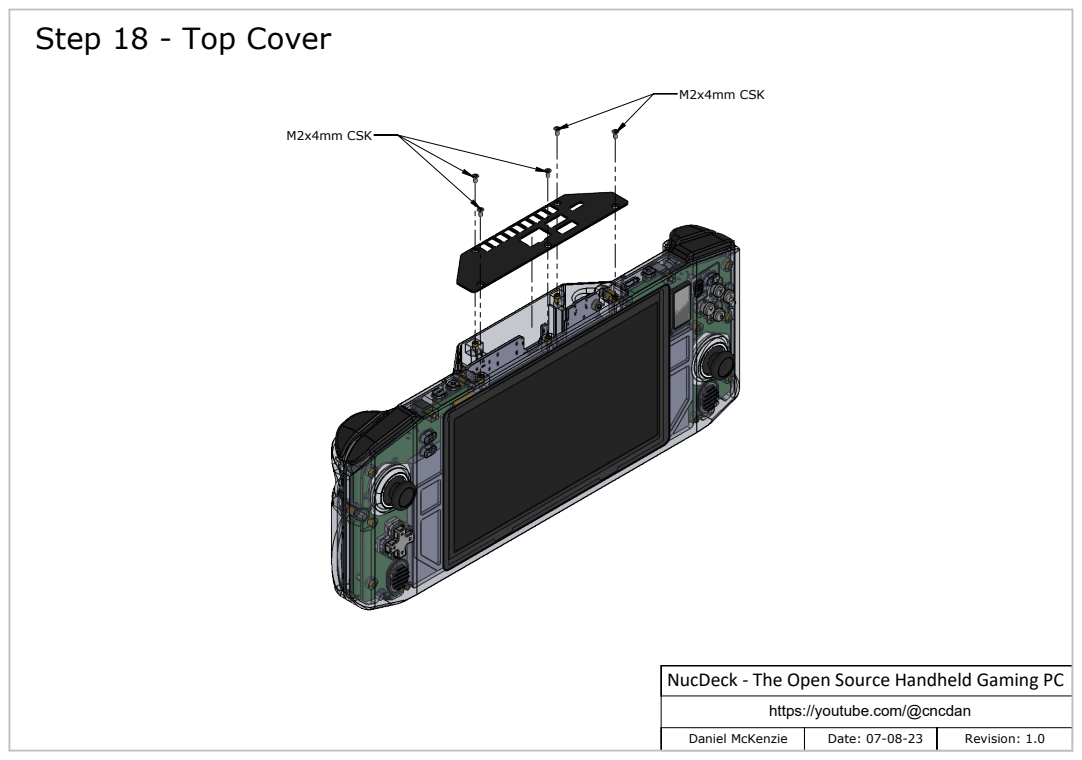
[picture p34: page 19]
M2x4mm CSK

Step 18 - Top Cover

NucDeck - The Open Source Handheld Gaming PC

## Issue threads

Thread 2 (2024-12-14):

This is amazing

quartexNOR, 2024-12-14:
I just found your videos since I had the same idea, and I just wanted to say that you have done some amazing work! Well done!
What would be cool is if you came up with a caddy system so that more computers could be used. A Nuc is great, but having a caddy so that Rock Pi 5b, Banana Pi 5, Raspberry Pi 5 and similar SBC's could be used -and you have single handedly solved portable gaming once and for all (!).

The challenge with devices like the Anbernic 565 and similar, is that they can never be updated. And they quickly cost €300 to €500 depending on model, shipping and import taxes.
Having a shell like your NucDeck can solve this.
It is large enough to handle a Nuc, which means a caddy / carrier where SBCs can be fastened and inserted should be possible.

I truly hope you pursue this, there is a real need for your solution out there. I'm a 51 year coder, and I want a machine that plays everything from Amiga to Ps3. But I am reluctant putting €700 to €1000 into a steamdeck. There has to be a way to recycle SBCs, or use a Nuc like you have done. And then I found your project.

If you come up with some way to put a Rock-Pi 5b in there, or a Raspberry pi 5, then this would be unbeatable. The retro community would love it.
Heck, you might consider producing them. I would much rather pay €400 for your deck, if I can recycle my SBCs.

I hope you think it over. Either way, super impressed by your skills!

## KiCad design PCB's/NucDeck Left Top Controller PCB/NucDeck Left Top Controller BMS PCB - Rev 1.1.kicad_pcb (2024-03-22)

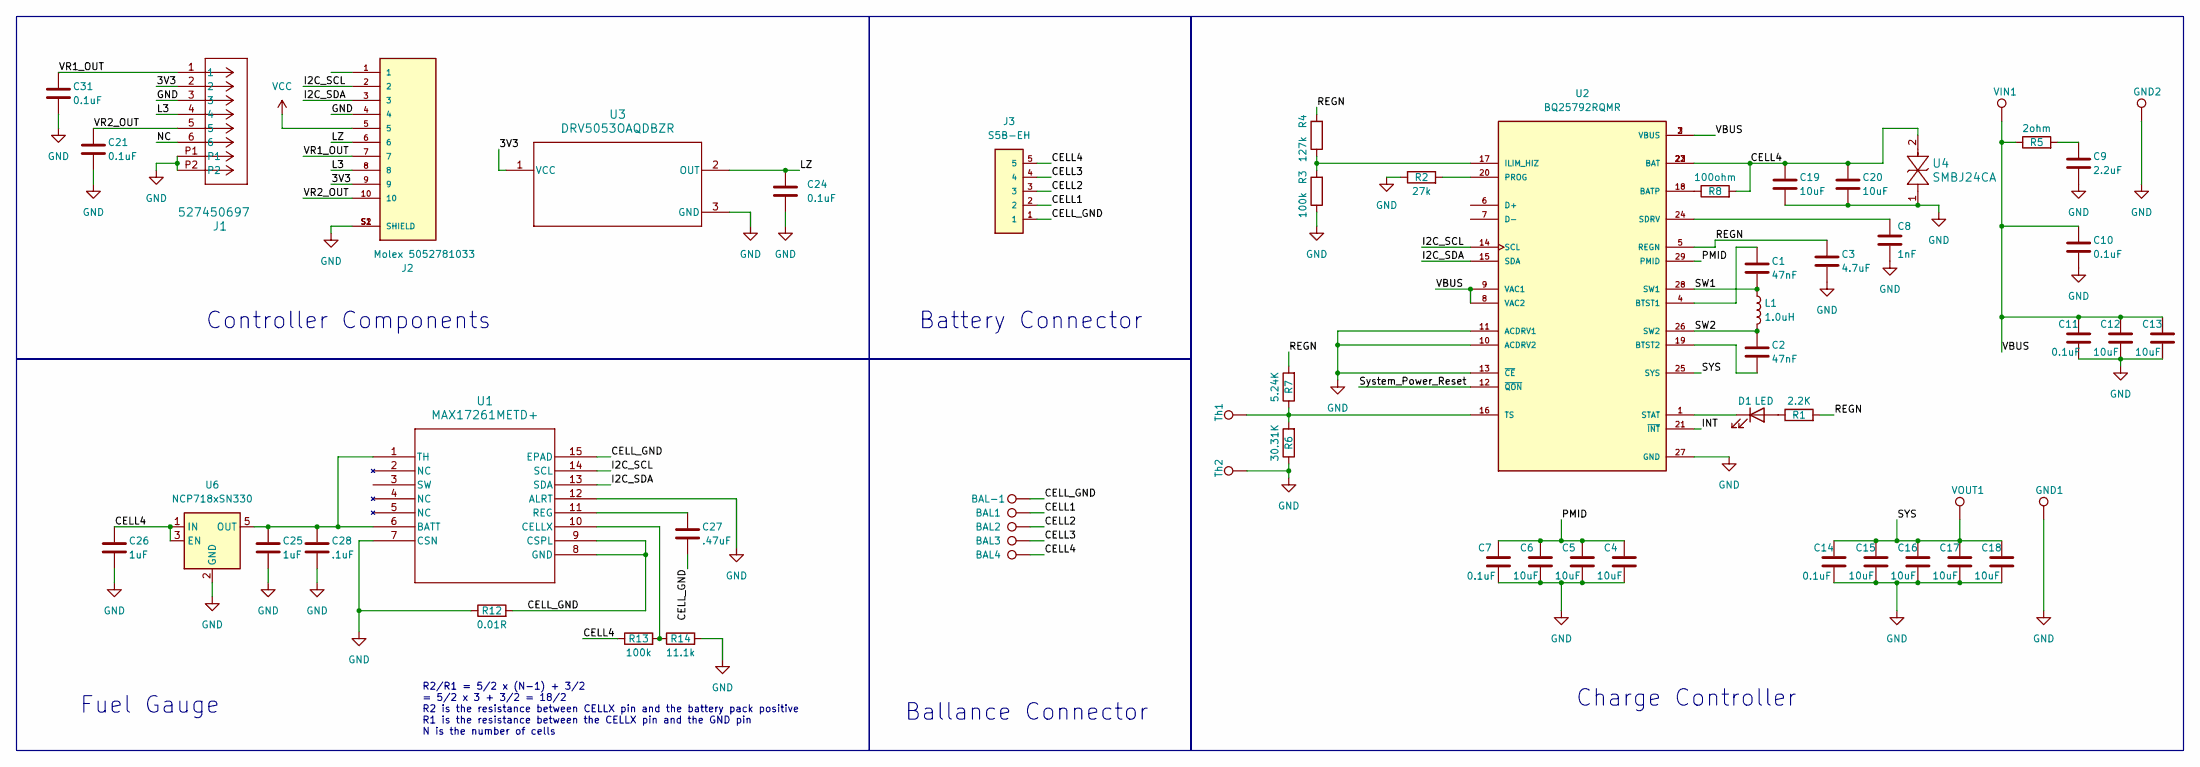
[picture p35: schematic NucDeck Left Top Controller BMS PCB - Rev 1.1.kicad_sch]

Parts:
BAL1, BAL2, BAL3, BAL4: TestPoint; TestPoint_Pad_1.0x1.0mm
BAL-1: TestPoint; TestPoint_Pad_1.0x1.0mm
C1, C2: 47nF; C_0603_1608Metric
C3: 4.7uF; C_0603_1608Metric
C4, C5, C6, C12, C13, C15, C16, C17, C18: 10uF; C_0805_2012Metric
C7, C10, C11, C14, C21, C24, C31: 0.1uF; C_0603_1608Metric
C8: 1nF; C_0603_1608Metric
C9: 2.2uF; C_0603_1608Metric
C19, C20: 10uF; C_0603_1608Metric
C25, C26: 1uF; C_0603_1608Metric
C27: .47uF; C_0603_1608Metric
C28: .1uF; C_0603_1608Metric
D1: LED; LED_0603_1608Metric
GND1, GND2: TestPoint; TestPoint_THTPad_D2.0mm_Drill1.0mm
J1: 527450697; CON_527450697_MOL
J2: Molex 5052781033; PARTREV A
J3: S5B-EH; JST_EH_S5B-EH_1x05_P2.50mm_Horizontal
L1: 1.0uH; IND_SPM6530_TDK
R1: 2.2K; R_0603_1608Metric
R2: 27k; R_0603_1608Metric
R3, R13: 100k; R_0603_1608Metric
R4: 127k; R_0603_1608Metric
R5: 2ohm; R_0603_1608Metric
R6: 30.31K; R_0603_1608Metric
R7: 5.24K; R_0603_1608Metric
R8: 100ohm; R_0603_1608Metric
R12: 0.01R; R_2512_6332Metric
R14: 11.1k; R_0603_1608Metric
Th1, Th2: 10K; TestPoint_THTPad_D1.0mm_Drill0.5mm
U1: MAX17261METD+; 21-0137_T1433+2C_MXM
U2: BQ25792RQMR; QFN40P400X400X100-29N; PARTREV 11/2019
U3: DRV5053OAQDBZR; DBZ0003A_N
U4: SMBJ24CA; SMBJ24CA_LTF
U6: NCP718xSN330; SOT-23-5
VIN1: TestPoint; TestPoint_THTPad_D2.0mm_Drill1.0mm
VOUT1: TestPoint; TestPoint_THTPad_D2.0mm_Drill1.0mm

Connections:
/3V3: J1.2, J2.9, U3.1 (VCC)
/CELL1: BAL1.1, J3.2
/CELL2: BAL2.1, J3.3
/CELL3: BAL3.1, J3.4
/CELL4: BAL4.1, C19.1, C20.1, C26.1, J3.5, R8.2, R13.1, U2.22 (BAT), U2.23 (BAT), U4.2, U6.1 (IN), U6.3 (EN)
/CELL_GND: BAL-1.1, C27.2, J3.1, R12.2, U1.8 (GND), U1.9 (CSPL), U1.15 (EPAD)
/I2C_SCL: J2.2, U1.14 (SCL), U2.14 (SCL)
/I2C_SDA: J2.3, U1.13 (SDA), U2.15 (SDA)
/INT: U2.21 (~INT)
/L3: J1.4, J2.8
/LZ: C24.1, J2.6, U3.2 (OUT)
/NC: J1.6
/PMID: C4.1, C5.1, C6.1, C7.1, U2.29 (PMID)
/REGN: C3.1, R1.2, R4.2, R7.2, U2.5 (REGN)
/SW1: C1.2, L1.1, U2.28 (SW1)
/SW2: C2.1, L1.2, U2.26 (SW2)
/SYS: C14.1, C15.1, C16.1, C17.1, C18.1, U2.25 (SYS), VOUT1.1; also elsewhere on the board
/System_Power_Reset: U2.12 (~QON)
/VBUS: C10.1, C11.1, C12.1, C13.1, R5.1, U2.2 (VBUS), U2.3 (VBUS), U2.8 (VAC2), U2.9 (VAC1), VIN1.1; also elsewhere on the board
/VR1_OUT: C31.1, J1.1, J2.7
/VR2_OUT: C21.1, J1.5, J2.10
GND: C3.2, C4.2, C5.2, C6.2, C7.2, C8.2, C9.2, C10.2, C11.2, C12.2, C13.2, C14.2, C15.2, C16.2, C17.2, C18.2, C19.2, C20.2, C21.2, C24.2, C25.2, C26.2, C28.2, C31.2, GND1.1, GND2.1, J1.3, J1.P1, J1.P2, J2.4, J2.11, J2.12, J2.S1 (SHIELD), J2.S2 (SHIELD), R2.1, R3.1, R6.1, R12.1, R14.2, Th2.1, U1.7 (CSN), U1.12 (ALRT), U2.10 (ACDRV2), U2.11 (ACDRV1), U2.13 (~CE), U2.27 (GND), U3.3 (GND), U4.1, U6.2 (GND); also elsewhere on the board
unnamed: C9.1, R5.2
unnamed: D1.2 (A), R1.1
unnamed: D1.1 (K), U2.1 (STAT)
unnamed: C25.1, C28.1, U1.1 (TH), U1.6 (BATT), U6.5 (OUT)
unnamed: R13.2, R14.1, U1.10 (CELLX)
unnamed: C27.1, U1.11 (REG)
unnamed: R8.1, U2.18 (BATP)
unnamed: C1.1, U2.4 (BTST1)
unnamed: C2.2, U2.19 (BTST2)
unnamed: R3.2, R4.1, U2.17 (ILIM_HIZ)
unnamed: R2.2, U2.20 (PROG)
unnamed: C8.1, U2.24 (SDRV)
unnamed: R6.2, R7.1, Th1.1, U2.16 (TS)
VCC: J2.5

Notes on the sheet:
Ballance Connector
Controller Components
Fuel Gauge
R2/R1 = 5/2 x (N-1) + 3/2 = 5/2 x 3 + 3/2 = 18/2 R2 is the resistance between CELLX pin and the battery pack positive R1 is the resistance between the CELLX pin and the GND pin N is the number of cells
Battery Connector
Charge Controller

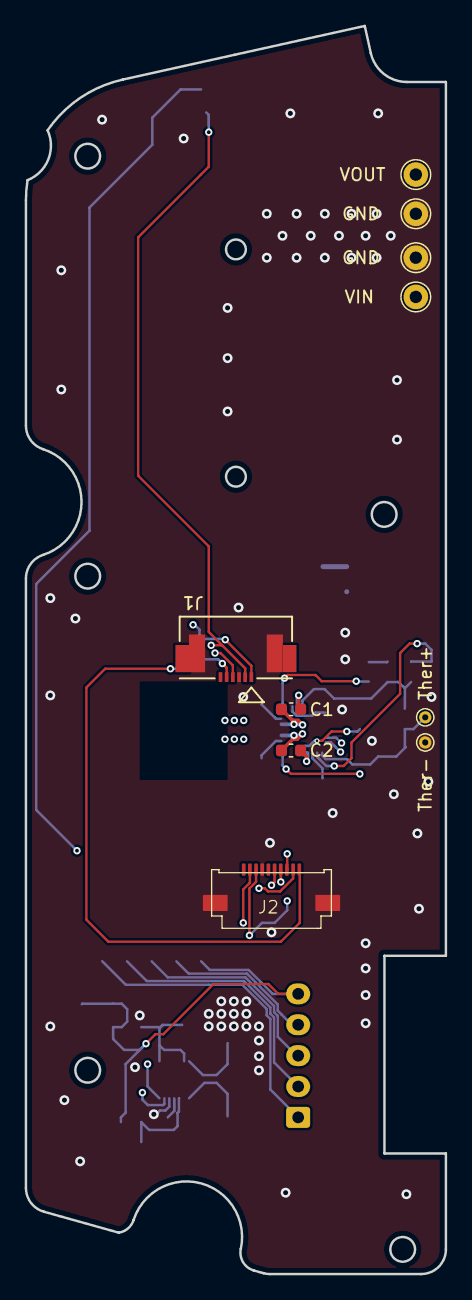
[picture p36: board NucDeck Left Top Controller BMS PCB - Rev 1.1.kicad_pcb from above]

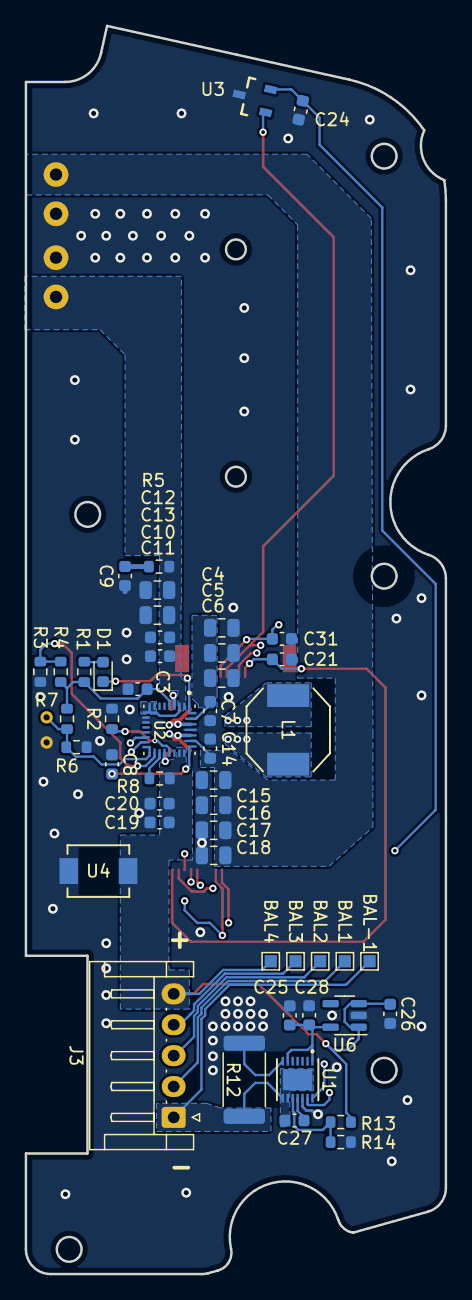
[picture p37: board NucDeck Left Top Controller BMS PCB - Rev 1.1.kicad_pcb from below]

Board: 4 copper layers, 34.0 x 101.0 mm, 59 parts (49 on the bottom side), 32 nets.

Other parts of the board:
GND: TestPoint; TestPoint_THTPad_D2.0mm_Drill1.0mm
GND#2: TestPoint; TestPoint_THTPad_D2.0mm_Drill1.0mm
VIN: TestPoint; TestPoint_THTPad_D2.0mm_Drill1.0mm
VOUT: TestPoint; TestPoint_THTPad_D2.0mm_Drill1.0mm

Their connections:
/SYS: VOUT.1; also elsewhere on the board
/VBUS: VIN.1; also elsewhere on the board
GND: GND.1, GND#2.1; also elsewhere on the board

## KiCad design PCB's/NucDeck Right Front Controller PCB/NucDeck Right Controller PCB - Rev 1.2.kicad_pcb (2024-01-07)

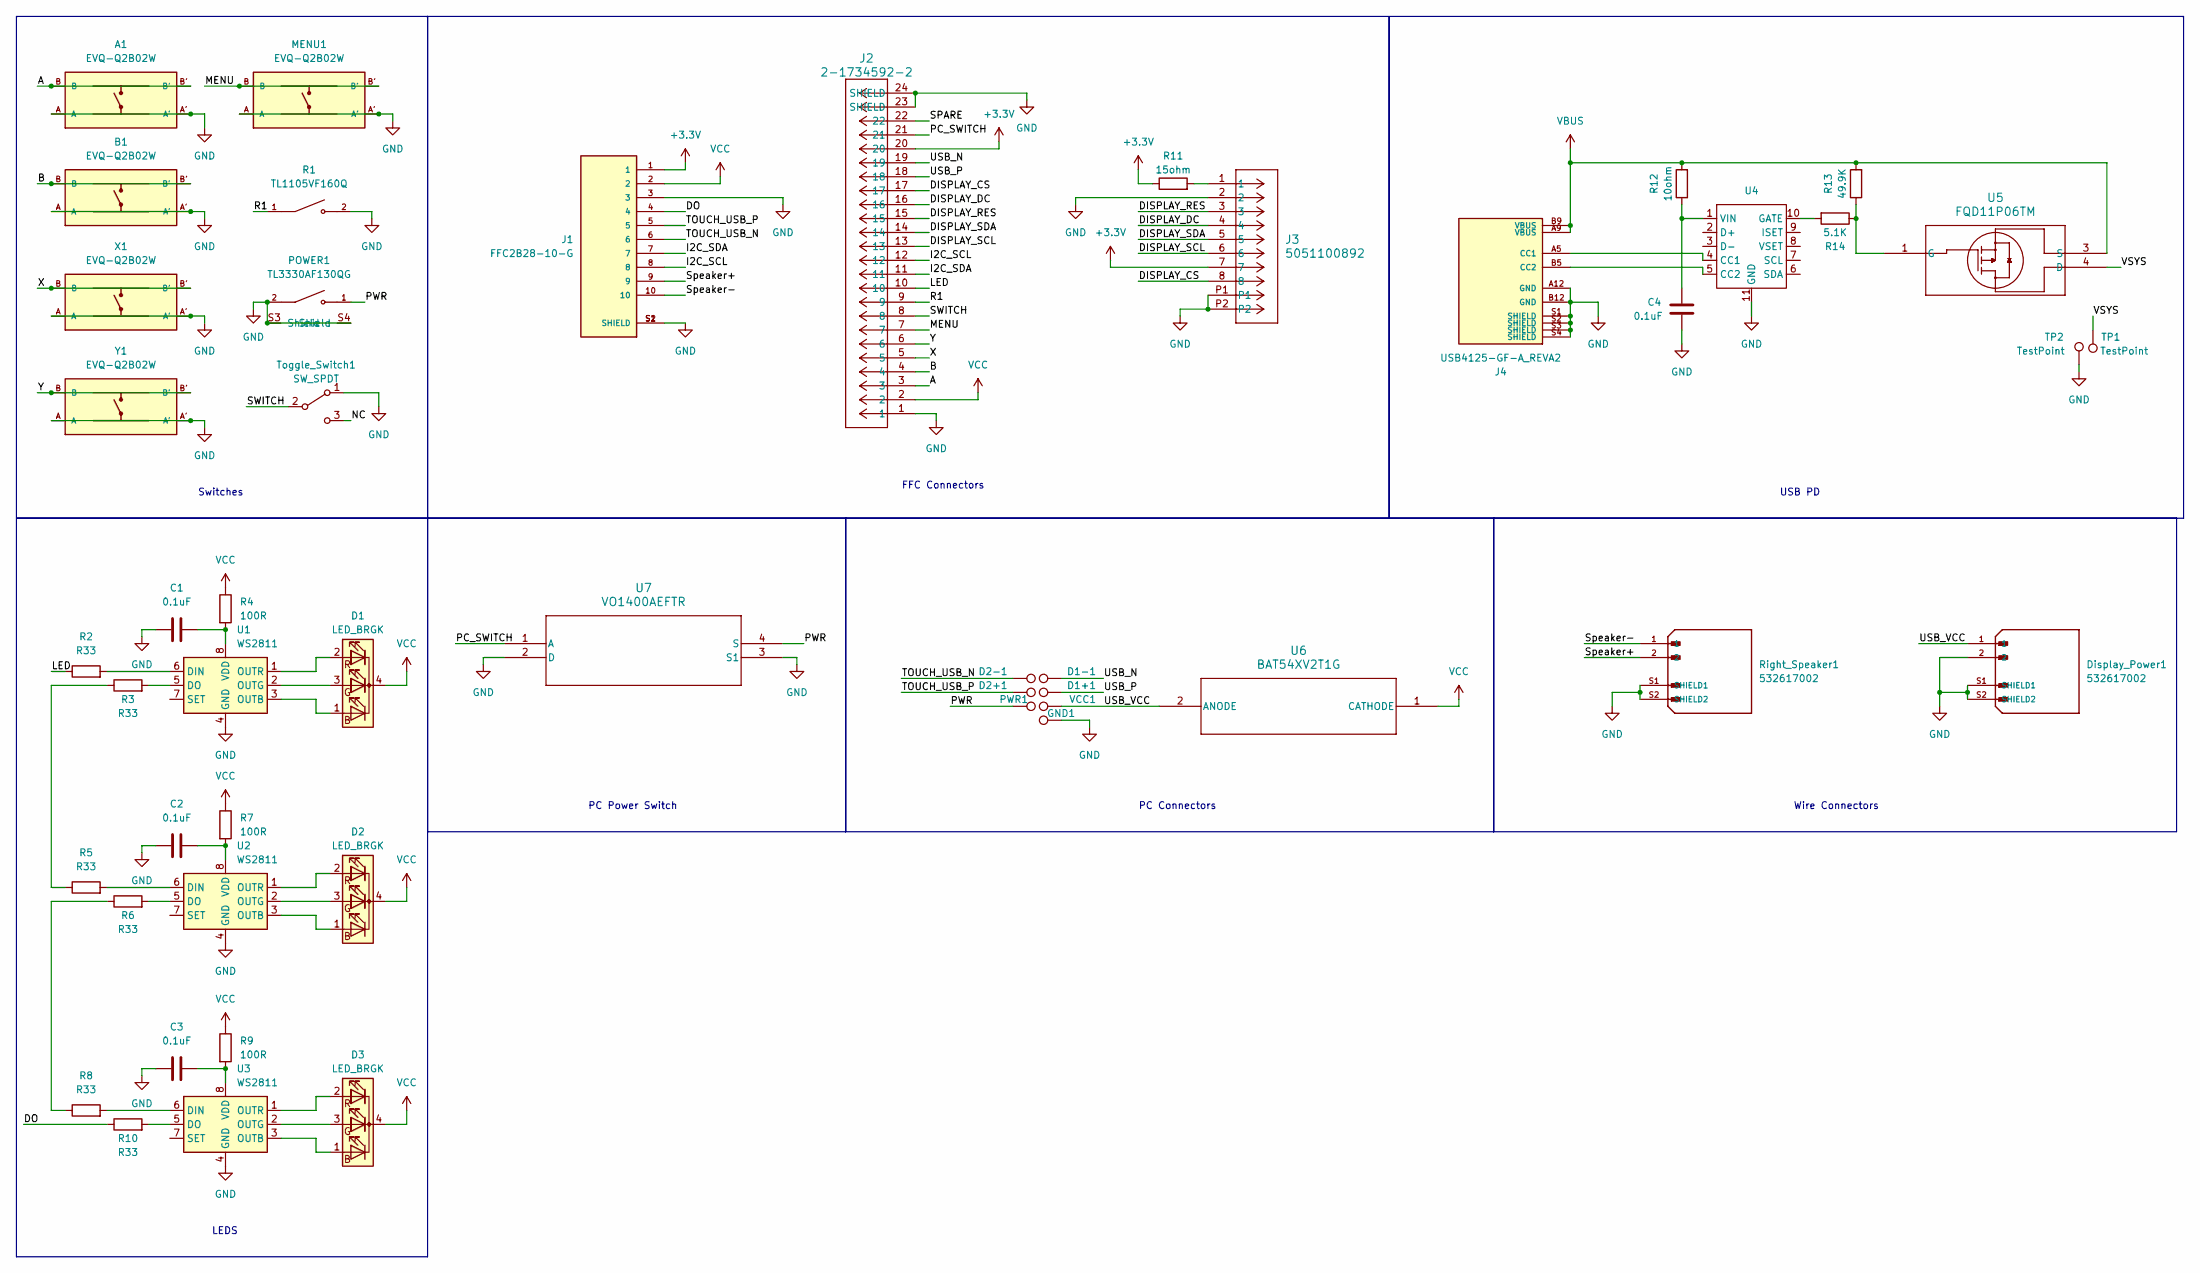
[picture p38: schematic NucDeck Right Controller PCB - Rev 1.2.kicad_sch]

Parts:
A1: EVQ-Q2B02W; SW_EVQ-Q2B02W
B1: EVQ-Q2B02W; SW_EVQ-Q2B02W
C1, C2, C3, C4: 0.1uF; C_0603_1608Metric_Pad1.08x0.95mm_HandSolder
D1, D2, D3: LED_BRGK; LED_T36K3BGR-05D000121U1930
D1+1, D1-1, D2+1, D2-1: TestPoint; TestPoint_THTPad_D1.0mm_Drill0.5mm
Display_Power1: 532617002; MOLEX_532617002; PARTREV B; DigiKey_Part_Number WM25389TR-ND
GND1: TestPoint; TestPoint_THTPad_D1.0mm_Drill0.5mm
J1: FFC2B28-10-G; Molex 5052781033; PARTREV A
J2: 2-1734592-2; CONN22_2-1734592-2
J3: 5051100892; CON_5051100892_MOL
J4: USB4125-GF-A_REVA2; GCT_USB4125-GF-A_REVA2; PARTREV Rev A2; DigiKey_Part_Number 2073-USB4125-GF-ATR-ND
MENU1: EVQ-Q2B02W; SW_EVQ-Q2B02W
POWER1: TL3330AF130QG; SW_TL3330AF130QG; PARTREV B
PWR1: TestPoint; TestPoint_THTPad_D1.0mm_Drill0.5mm
R1: TL1105VF160Q; SW_TL1105VF160Q; PARTREV C
R2, R3, R5, R6, R8, R10: R33; R_0603_1608Metric_Pad0.98x0.95mm_HandSolder
R4, R7, R9: 100R; R_0603_1608Metric_Pad0.98x0.95mm_HandSolder
R11: 15ohm; R_0603_1608Metric_Pad0.98x0.95mm_HandSolder
R12: 10ohm; R_0603_1608Metric_Pad0.98x0.95mm_HandSolder
R13: 49.9K; R_0603_1608Metric_Pad0.98x0.95mm_HandSolder
R14: 5.1K; R_0603_1608Metric_Pad0.98x0.95mm_HandSolder
Right_Speaker1: 532617002; MOLEX_532617002; PARTREV B; DigiKey_Part_Number WM25389TR-ND
TP1, TP2: TestPoint; TestPoint_THTPad_D1.5mm_Drill0.7mm
Toggle_Switch1: SW_SPDT; NKK SS12SBP2
U1, U2, U3: WS2811; SOP-8_3.9x4.9mm_P1.27mm
U4: DFN-10-1EP_3x3mm_P0.5mm_EP1.7x2.5mm
U5: FQD11P06TM; TO-252-3_ONS
U6: BAT54XV2T1G; SOD-523_0P9X1P3_ONS
U7: VO1400AEFTR; SO-4_VO_VIS
VCC1: TestPoint; TestPoint_THTPad_D1.0mm_Drill0.5mm
X1: EVQ-Q2B02W; SW_EVQ-Q2B02W
Y1: EVQ-Q2B02W; SW_EVQ-Q2B02W

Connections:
+3.3V: J1.1, J2.20, J3.7, R11.1
/A: A1.B, A1.B', J2.3
/B: B1.B, B1.B', J2.4
/DISPLAY_CS: J2.17, J3.8
/DISPLAY_DC: J2.16, J3.4
/DISPLAY_RES: J2.15, J3.3
/DISPLAY_SCL: J2.13, J3.6
/DISPLAY_SDA: J2.14, J3.5
/DO: J1.4, R10.1
/I2C_SCL: J1.8, J2.12
/I2C_SDA: J1.7, J2.11
/LED: J2.10, R2.1
/MENU: J2.7, MENU1.B, MENU1.B'
/NC: Toggle_Switch1.3 (C)
/PC_SWITCH: J2.21, U7.1 (A)
/PWR: POWER1.1, PWR1.1, U7.4 (S)
/R1: J2.9, R1.1
/SPARE: J2.22
/SWITCH: J2.8, Toggle_Switch1.2 (B)
/Speaker+: J1.9, Right_Speaker1.2
/Speaker-: J1.10, Right_Speaker1.1
/TOUCH_USB_N: D2-1.1, J1.6
/TOUCH_USB_P: D2+1.1, J1.5
/USB_N: D1-1.1, J2.19
/USB_P: D1+1.1, J2.18
/USB_VCC: Display_Power1.1, U6.2 (ANODE), VCC1.1
/VSYS: TP1.1, U5.4 (D)
/X: J2.5, X1.B, X1.B'
/Y: J2.6, Y1.B, Y1.B'
GND: A1.A, A1.A', B1.A, B1.A', C1.1, C2.1, C3.1, C4.2, Display_Power1.2, Display_Power1.S1 (SHIELD1), Display_Power1.S2 (SHIELD2), GND1.1, J1.3, J1.11, J1.12, J1.S1 (SHIELD), J1.S2 (SHIELD), J2.1, J2.23 (SHIELD), J2.24 (SHIELD), J3.2, J3.P1, J3.P2, J4.1, J4.2, J4.3, J4.4, J4.A12 (GND), J4.B12 (GND), J4.S1 (SHIELD), J4.S2 (SHIELD), J4.S3 (SHIELD), J4.S4 (SHIELD), MENU1.A, MENU1.A', POWER1.2, POWER1.S1, POWER1.S3 (Shield), POWER1.S4 (Shield), R1.2, R1.S1, R1.S2, Right_Speaker1.S1 (SHIELD1), Right_Speaker1.S2 (SHIELD2), TP2.1, Toggle_Switch1.1 (A), U1.4 (GND), U2.4 (GND), U3.4 (GND), U4.11 (GND), U7.2 (D), U7.3 (S1), X1.A, X1.A', Y1.A, Y1.A'
unnamed: D1.1 (BA), U1.3 (OUTB)
unnamed: D1.3 (GA), U1.2 (OUTG)
unnamed: D1.2 (RA), U1.1 (OUTR)
unnamed: D2.1 (BA), U2.3 (OUTB)
unnamed: D2.3 (GA), U2.2 (OUTG)
unnamed: D2.2 (RA), U2.1 (OUTR)
unnamed: D3.1 (BA), U3.3 (OUTB)
unnamed: D3.3 (GA), U3.2 (OUTG)
unnamed: D3.2 (RA), U3.1 (OUTR)
unnamed: J3.1, R11.2
unnamed: J4.A5 (CC1), U4.4 (CC1)
unnamed: J4.B5 (CC2), U4.5 (CC2)
unnamed: R3.1, R5.1
unnamed: R6.1, R8.1
unnamed: R2.2, U1.6 (DIN)
unnamed: R3.2, U1.5 (DO)
unnamed: C1.2, R4.2, U1.8 (VDD)
unnamed: R5.2, U2.6 (DIN)
unnamed: R6.2, U2.5 (DO)
unnamed: C2.2, R7.2, U2.8 (VDD)
unnamed: R8.2, U3.6 (DIN)
unnamed: R10.2, U3.5 (DO)
unnamed: C3.2, R9.2, U3.8 (VDD)
unnamed: R14.2, U4.10 (GATE)
unnamed: C4.1, R12.1, U4.1 (VIN)
unnamed: R13.1, R14.1, U5.1 (G)
VBUS: J4.A9 (VBUS), J4.B9 (VBUS), R12.2, R13.2, U5.3 (S)
VCC: D1.4 (K), D2.4 (K), D3.4 (K), J1.2, J2.2, R4.1, R7.1, R9.1, U6.1 (CATHODE)

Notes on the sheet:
Switches
PC Power Switch
PC Connectors
FFC Connectors
LEDS
USB PD
Wire Connectors

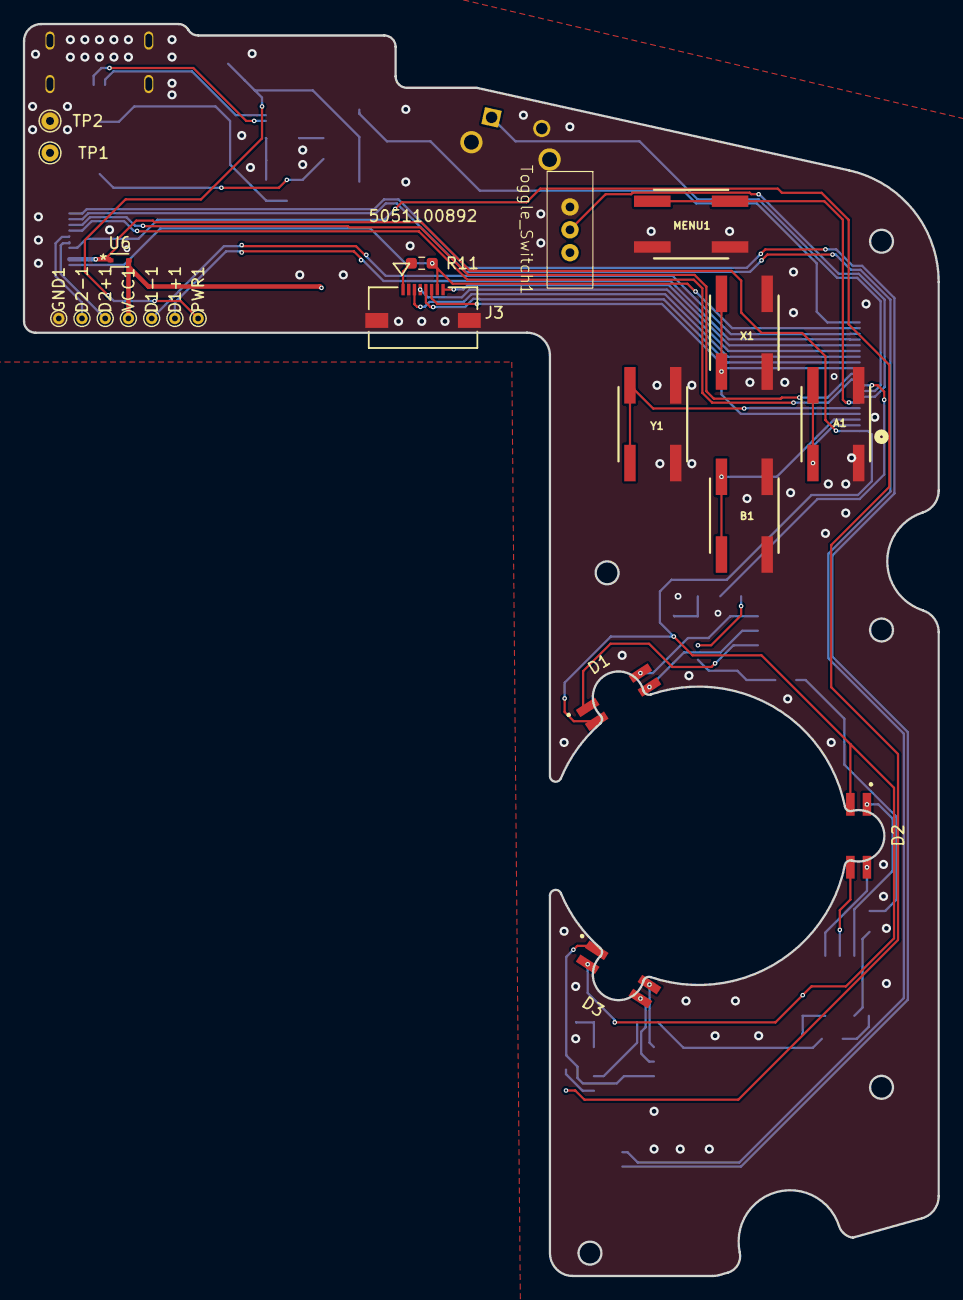
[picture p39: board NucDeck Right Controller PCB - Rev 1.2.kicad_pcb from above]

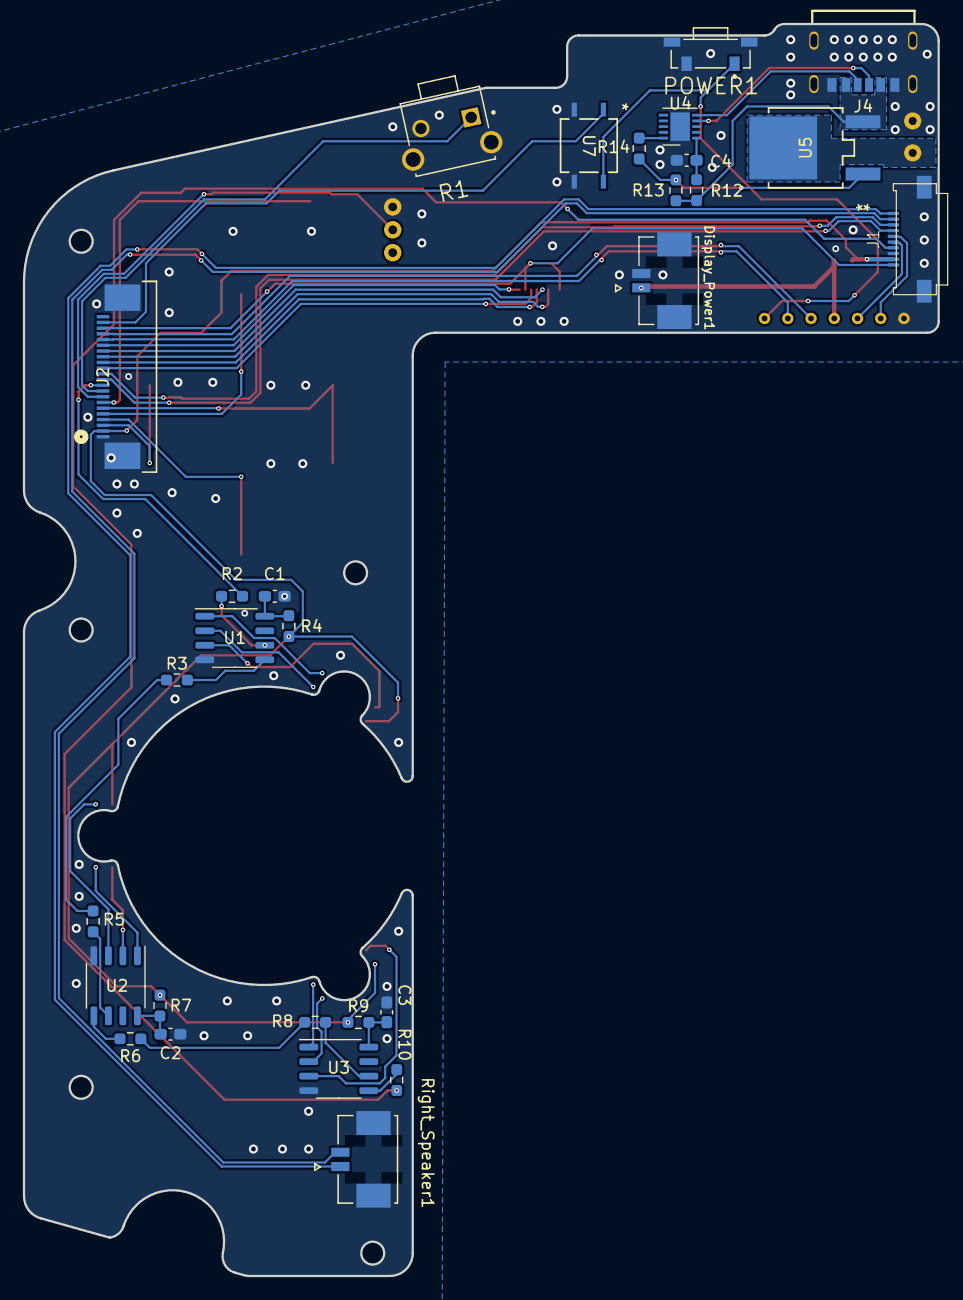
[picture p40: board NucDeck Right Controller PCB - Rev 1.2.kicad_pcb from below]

Board: 2 copper layers, 80.0 x 109.5 mm, 50 parts (29 on the bottom side), 56 nets.

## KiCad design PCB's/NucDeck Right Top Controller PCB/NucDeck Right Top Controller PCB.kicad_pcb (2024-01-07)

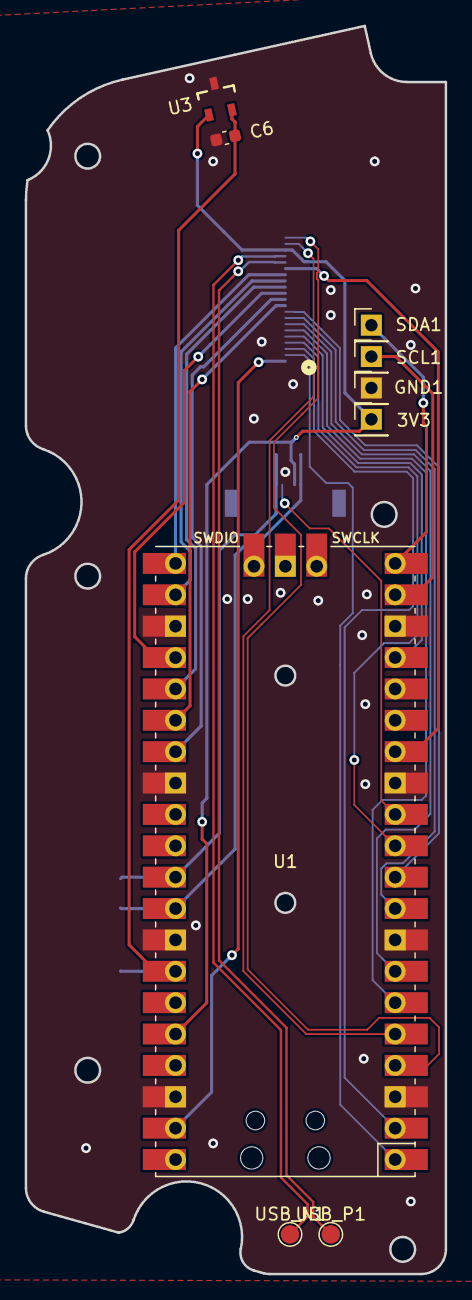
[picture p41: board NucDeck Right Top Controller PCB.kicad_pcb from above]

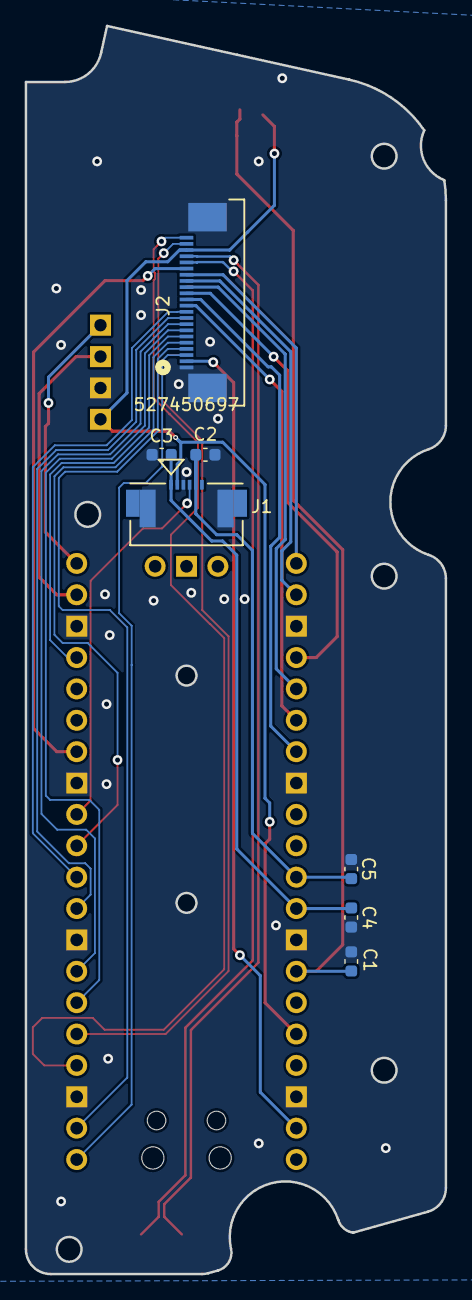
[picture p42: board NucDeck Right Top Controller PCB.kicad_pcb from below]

Board: 2 copper layers, 34.0 x 101.0 mm, 16 parts (7 on the bottom side), 28 nets.

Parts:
3V3: TestPoint; PinHeader_1x01_P2.54mm_Vertical
C1, C2, C3, C4, C5, C6: 0.1uF; C_0603_1608Metric
GND1: TestPoint; PinHeader_1x01_P2.54mm_Vertical
J1: 527450697; CON_527450697_MOL
J2: 2-1734592-2; CONN22_2-1734592-2
SCL1: TestPoint; PinHeader_1x01_P2.54mm_Vertical
SDA1: TestPoint; PinHeader_1x01_P2.54mm_Vertical
U1: Pico; RPi_Pico_SMD_TH
U3: DRV5053OAQDBZR; DBZ0003A_N
USB_N1: TestPoint; TestPoint_Pad_D1.5mm
USB_P1: TestPoint; TestPoint_Pad_D1.5mm

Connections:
+3.3V: 3V3.1, J1.2, J2.20, U1.36 (3V3), U3.1 (VCC)
/A: J2.3, U1.1 (GPIO0)
/B: J2.4, U1.2 (GPIO1)
/DISPLAY_CS: J2.17, U1.14 (GPIO10)
/DISPLAY_DC: J2.16, U1.21 (GPIO16)
/DISPLAY_RES: J2.15, U1.22 (GPIO17)
/DISPLAY_SCL: J2.13, U1.24 (GPIO18)
/DISPLAY_SDA: J2.14, U1.25 (GPIO19)
/I2C_SCL: J2.12, U1.27 (GPIO21)
/I2C_SDA: J2.11, U1.26 (GPIO20)
/LED: J2.10, U1.10 (GPIO7)
/MENU: J2.7, U1.6 (GPIO4)
/MPU6050_SCL: SDA1.1, U1.20 (GPIO15)
/MPU6050_SDA: SCL1.1, U1.19 (GPIO14)
/PC_SWITCH: J2.21, U1.5 (GPIO3)
/R1: J2.9, U1.9 (GPIO6)
/R3: J1.4, U1.12 (GPIO9)
/RZ: C1.1, C6.1, U1.34 (GPIO28_ADC2), U3.2 (OUT)
/SPARE: J2.22, U1.4 (GPIO2)
/SWITCH: J2.8, U1.7 (GPIO5)
/USB_N: J2.19, USB_N1.1
/USB_P: J2.18, USB_P1.1
/VR1_OUT: C3.1, C4.1, J1.1, U1.32 (GPIO27_ADC1)
/VR2_OUT: C2.1, C5.1, J1.5, U1.31 (GPIO26_ADC0)
/X: J2.5, U1.11 (GPIO8)
/Y: J2.6, U1.17 (GPIO13)
GND: C1.2, C2.2, C3.2, C4.2, C5.2, C6.2, GND1.1, J1.3, J1.P1, J1.P2, J2.1, J2.23 (SHIELD), J2.24 (SHIELD), U1.3 (GND), U1.8 (GND), U1.13 (GND), U1.18 (GND), U1.23 (GND), U1.28 (GND), U1.33 (AGND), U1.38 (GND), U3.3 (GND)
VCC: J2.2, U1.39 (VSYS)

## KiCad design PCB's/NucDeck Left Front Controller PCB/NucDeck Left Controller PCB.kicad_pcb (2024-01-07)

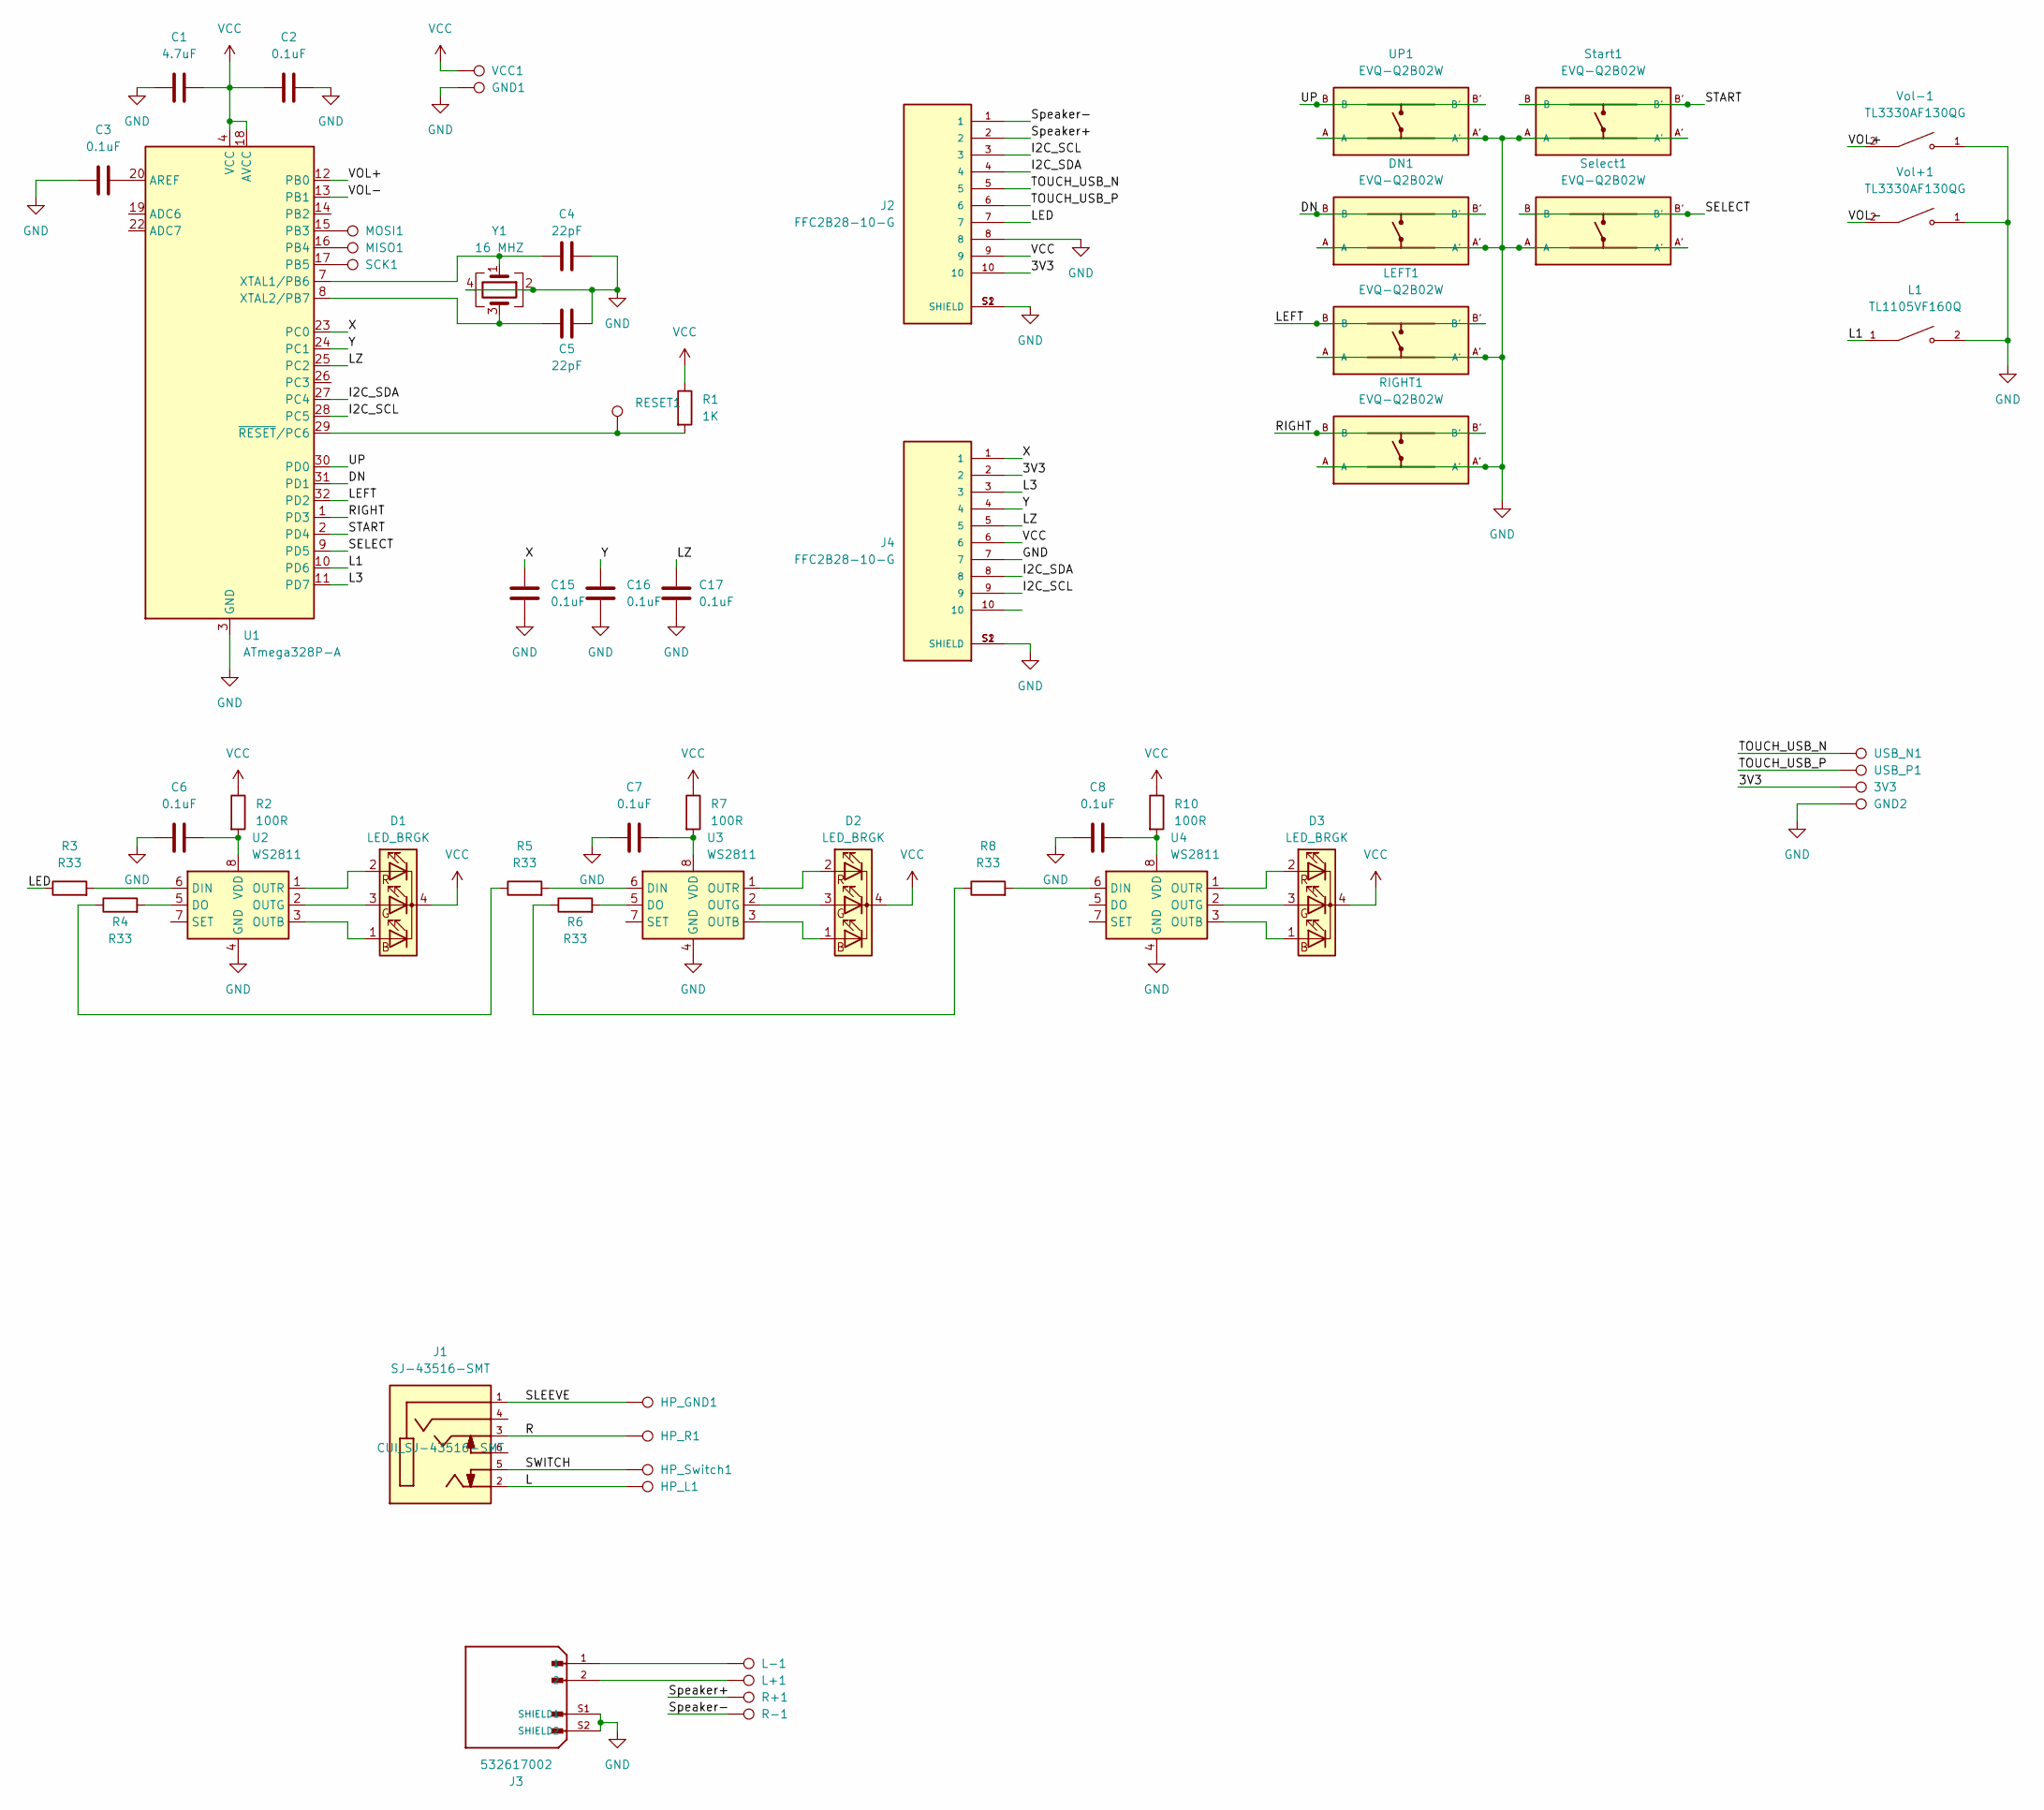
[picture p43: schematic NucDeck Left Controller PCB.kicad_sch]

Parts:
3V3: 3V3; TestPoint_THTPad_D1.5mm_Drill0.7mm
C1: 4.7uF; C_0603_1608Metric_Pad1.08x0.95mm_HandSolder
C2, C3, C6, C7, C8, C15, C16, C17: 0.1uF; C_0603_1608Metric_Pad1.08x0.95mm_HandSolder
C4, C5: 22pF; C_0603_1608Metric_Pad1.08x0.95mm_HandSolder
D1, D2, D3: LED_BRGK; LED_T36K3BGR-05D000121U1930
DN1: EVQ-Q2B02W; SW_EVQ-Q2B02W
GND1: GND; TestPoint_Pad_D1.5mm
GND2: GND; TestPoint_THTPad_D1.5mm_Drill0.7mm
HP_GND1: TestPoint_Pad_1.0x1.0mm
HP_L1: TestPoint_Pad_1.0x1.0mm
HP_R1: TestPoint_Pad_1.0x1.0mm
HP_Switch1: TestPoint_Pad_1.0x1.0mm
J1: SJ-43516-SMT; CUI_SJ-43516-SMT; PART_REV 1.02
J2, J4: FFC2B28-10-G; GCT_FFC2B28-10-G; PARTREV A
J3: 532617002; MOLEX_532617002; PARTREV B; DigiKey_Part_Number WM25389TR-ND
L1: TL1105VF160Q; SW_TL1105VF160Q; PARTREV C
L+1: TestPoint_Pad_1.0x1.0mm
L-1: TestPoint_Pad_1.0x1.0mm
LEFT1: EVQ-Q2B02W; SW_EVQ-Q2B02W
MISO1: MISO; TestPoint_Pad_D1.5mm
MOSI1: MOSI; TestPoint_Pad_D1.5mm
R1: 1K; R_0603_1608Metric_Pad0.98x0.95mm_HandSolder
R2, R7, R10: 100R; R_0603_1608Metric_Pad0.98x0.95mm_HandSolder
R3, R4, R5, R6, R8: R33; R_0603_1608Metric_Pad0.98x0.95mm_HandSolder
R+1: TestPoint_Pad_1.0x1.0mm
R-1: TestPoint_Pad_1.0x1.0mm
RESET1: RESET; TestPoint_Pad_D1.5mm
RIGHT1: EVQ-Q2B02W; SW_EVQ-Q2B02W
SCK1: SCK; TestPoint_Pad_D1.5mm
Select1: EVQ-Q2B02W; SW_EVQ-Q2B02W
Start1: EVQ-Q2B02W; SW_EVQ-Q2B02W
U1: ATmega328P-A; TQFP-32_7x7mm_P0.8mm
U2, U3, U4: WS2811; SOP-8_3.9x4.9mm_P1.27mm
UP1: EVQ-Q2B02W; SW_EVQ-Q2B02W
USB_N1: USB_N; TestPoint_THTPad_D1.5mm_Drill0.7mm
USB_P1: USB_P; TestPoint_THTPad_D1.5mm_Drill0.7mm
VCC1: VCC; TestPoint_Pad_D1.5mm
Vol+1: TL3330AF130QG; SW_TL3330AF130QG; PARTREV B
Vol-1: TL3330AF130QG; SW_TL3330AF130QG; PARTREV B
Y1: 16 MHZ; Crystal_SMD_5032-4Pin_5.0x3.2mm

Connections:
/3V3: 3V3.1, J2.10, J4.2
/DN: DN1.B, DN1.B', U1.31 (PD1)
/I2C_SCL: J2.3, J4.9, U1.28 (PC5)
/I2C_SDA: J2.4, J4.8, U1.27 (PC4)
/L: HP_L1.1, J1.2
/L1: L1.1, U1.10 (PD6)
/L3: J4.3, U1.11 (PD7)
/LED: J2.7, R3.1
/LEFT: LEFT1.B, LEFT1.B', U1.32 (PD2)
/LZ: C17.2, J4.5, U1.25 (PC2)
/R: HP_R1.1, J1.3
/RIGHT: RIGHT1.B, RIGHT1.B', U1.1 (PD3)
/SELECT: Select1.B, Select1.B', U1.9 (PD5)
/SLEEVE: HP_GND1.1, J1.1
/START: Start1.B, Start1.B', U1.2 (PD4)
/SWITCH: HP_Switch1.1, J1.5
/Speaker+: J2.2, R+1.1
/Speaker-: J2.1, R-1.1
/TOUCH_USB_N: J2.5, USB_N1.1
/TOUCH_USB_P: J2.6, USB_P1.1
/UP: U1.30 (PD0), UP1.B, UP1.B'
/VOL+: U1.12 (PB0), Vol-1.2
/VOL-: U1.13 (PB1), Vol+1.2
/X: C15.2, J4.1, U1.23 (PC0)
/Y: C16.2, J4.4, U1.24 (PC1)
GND: C1.1, C2.2, C3.1, C4.2, C5.2, C6.1, C7.1, C8.1, C15.1, C16.1, C17.1, DN1.A, DN1.A', GND1.1, GND2.1, J2.8, J2.11, J2.12, J2.S1 (SHIELD), J2.S2 (SHIELD), J3.S1 (SHIELD1), J3.S2 (SHIELD2), J4.7, J4.11, J4.12, J4.S1 (SHIELD), J4.S2 (SHIELD), L1.2, LEFT1.A, LEFT1.A', RIGHT1.A, RIGHT1.A', Select1.A, Select1.A', Start1.A, Start1.A', U1.3 (GND), U1.5 (GND), U1.21 (GND), U2.4 (GND), U3.4 (GND), U4.4 (GND), UP1.A, UP1.A', Vol+1.1, Vol+1.S1, Vol+1.S2, Vol-1.1, Vol-1.S1, Vol-1.S2, Y1.2, Y1.4
unnamed: D1.1 (BA), U2.3 (OUTB)
unnamed: D1.3 (GA), U2.2 (OUTG)
unnamed: D1.2 (RA), U2.1 (OUTR)
unnamed: D2.1 (BA), U3.3 (OUTB)
unnamed: D2.3 (GA), U3.2 (OUTG)
unnamed: D2.2 (RA), U3.1 (OUTR)
unnamed: D3.1 (BA), U4.3 (OUTB)
unnamed: D3.3 (GA), U4.2 (OUTG)
unnamed: D3.2 (RA), U4.1 (OUTR)
unnamed: J3.1, L-1.1
unnamed: J3.2, L+1.1
unnamed: R4.1, R5.1
unnamed: R6.1, R8.1
unnamed: C3.2, U1.20 (AREF)
unnamed: MOSI1.1, U1.15 (PB3)
unnamed: MISO1.1, U1.16 (PB4)
unnamed: SCK1.1, U1.17 (PB5)
unnamed: C4.1, U1.7 (XTAL1/PB6), Y1.1
unnamed: C5.1, U1.8 (XTAL2/PB7), Y1.3
unnamed: R1.2, RESET1.1, U1.29 (~RESET/PC6)
unnamed: R3.2, U2.6 (DIN)
unnamed: R4.2, U2.5 (DO)
unnamed: C6.2, R2.2, U2.8 (VDD)
unnamed: R5.2, U3.6 (DIN)
unnamed: R6.2, U3.5 (DO)
unnamed: C7.2, R7.2, U3.8 (VDD)
unnamed: R8.2, U4.6 (DIN)
unnamed: C8.2, R10.2, U4.8 (VDD)
VCC: C1.2, C2.1, D1.4 (K), D2.4 (K), D3.4 (K), J2.9, J4.6, R1.1, R2.1, R7.1, R10.1, U1.4 (VCC), U1.6 (VCC), U1.18 (AVCC), VCC1.1

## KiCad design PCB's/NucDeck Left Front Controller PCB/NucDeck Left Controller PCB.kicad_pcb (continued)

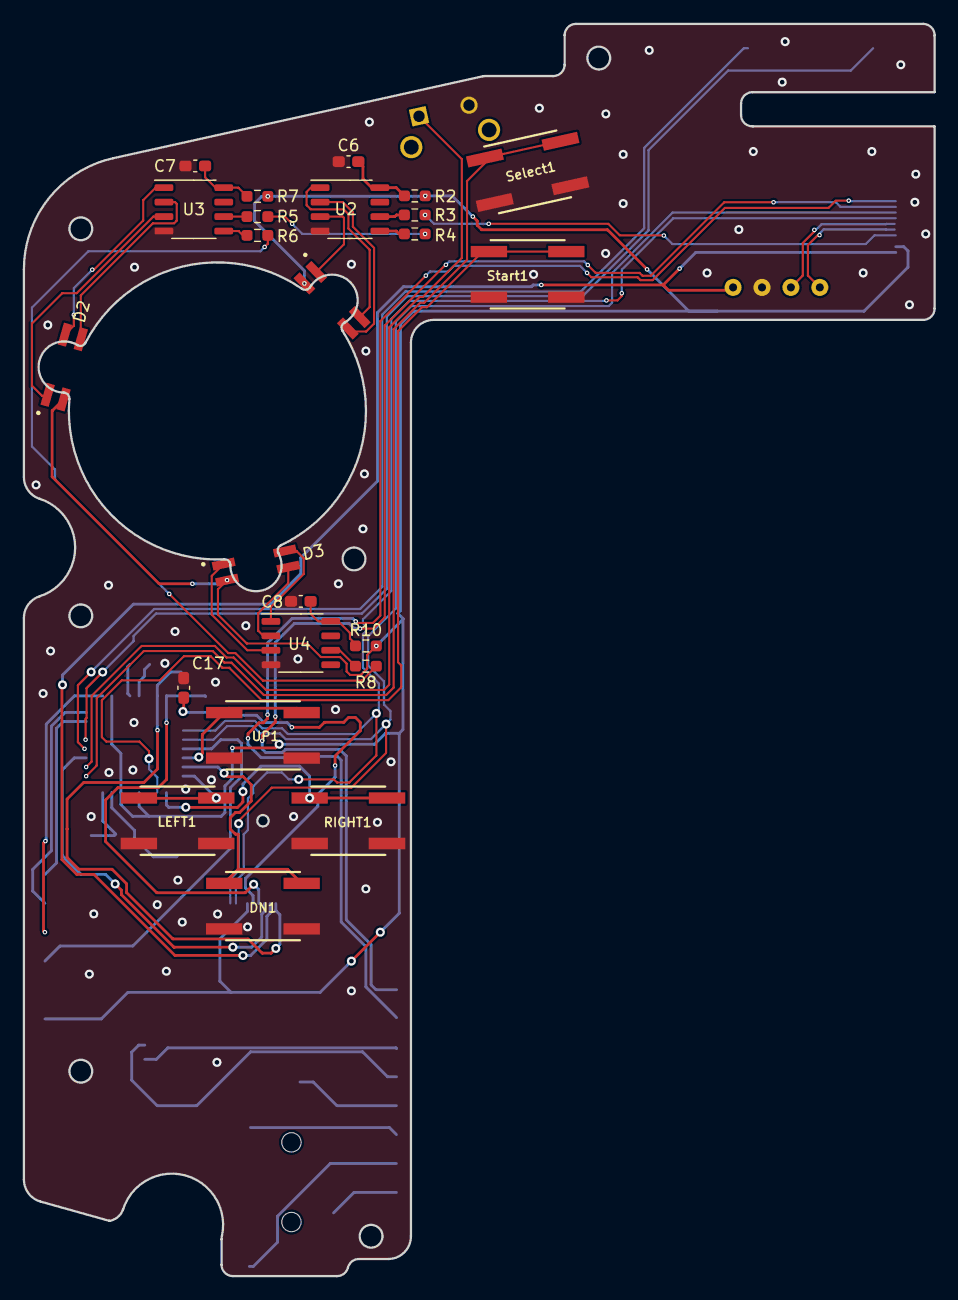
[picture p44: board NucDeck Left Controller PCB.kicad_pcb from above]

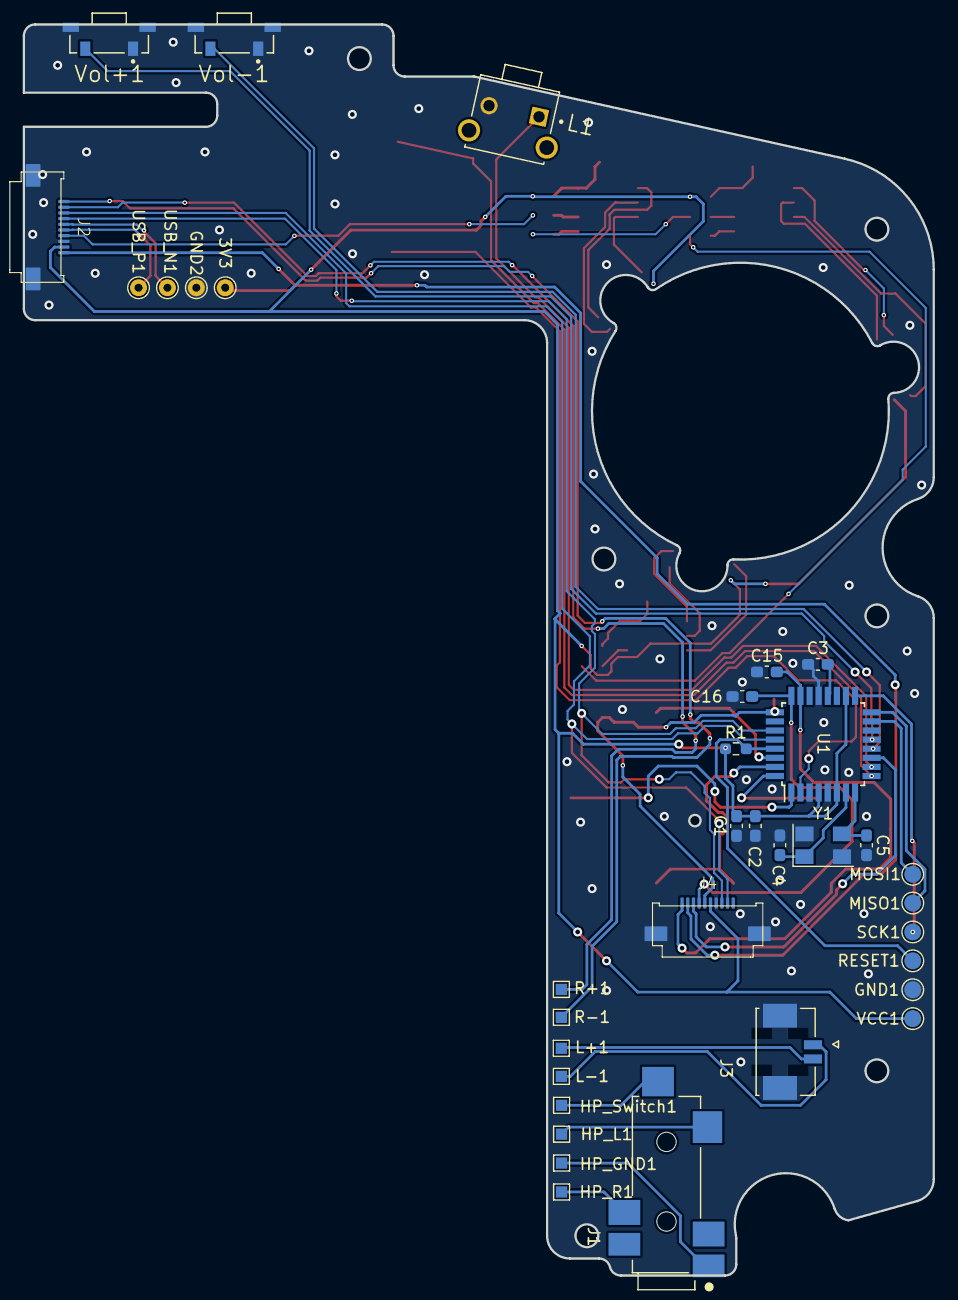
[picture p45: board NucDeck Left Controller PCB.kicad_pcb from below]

Board: 2 copper layers, 80.0 x 110.0 mm, 59 parts (35 on the bottom side), 55 nets.

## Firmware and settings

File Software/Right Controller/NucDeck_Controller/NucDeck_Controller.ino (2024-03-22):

/*
 * NUCDeck Controller - V1.0
 * Daniel McKenzie - 21st March 2024
 * 
 */
#include <Wire.h>
#include <FastLED.h>
#include <EEPROM.h>
#include <Joystick.h>
#include <Keyboard.h>
#include <Mouse.h>
#include <TFT_eSPI.h>
#include "images.h" //XBM Images

//I2C Controller Addresses
byte controllerAddr = 0x01;         //i2c Address of other half of controller
byte buttons = 0xF1;                //Register for buttons
byte xAxis = 0xF2;                  //Register for X Axis
byte yAxis = 0xF3;                  //Register for Y Axis
byte zAxis = 0xF4;                  //Register for Z Axis
const byte CONTROLLER_I2C_SDA = 20; //SDA pin for other controller half
const byte CONTROLLER_I2C_SCL = 21; //SCL pin for other controller half
int i2cButtonCount = 10;            //Number of buttons on i2c

//MPU6050
const int MPU6050 = 0x68;
const byte MPU6050_SDA = 14;
const byte MPU6050_SCL = 15;
float AccX, AccY, AccZ;
float GyroX, GyroY, GyroZ;
float GyroLastX, GyroLastY, GyroLastZ;
float accAngleX, accAngleY, gyroAngleX, gyroAngleY, gyroAngleZ;
float roll, pitch, yaw;
float AccErrorX, AccErrorY, GyroErrorX, GyroErrorY, GyroErrorZ;
float elapsedTime, currentTime, previousTime;
int c = 0;
int xOffset = 0;
int yOffset = 0;
unsigned long gyroTimer;

//Default Joystick calibration settings and EEPROM storage Address
int minLeftX = 129; //EEPROM Adr = 1
int maxLeftX = 590; //EEPROM Adr = 3
int midLeftX = 362; //EEPROM Adr = 5

int minLeftY = 144; //EEPROM Adr = 7
int maxLeftY = 600; //EEPROM Adr = 9
int midLeftY = 372; //EEPROM Adr = 11

int minRightY = 225; //EEPROM Adr = 13
int maxRightY = 810; //EEPROM Adr = 15
int midRightY = 482; //EEPROM Adr = 17

int minRightX = 180; //EEPROM Adr = 19
int maxRightX = 760; //EEPROM Adr = 21
int midRightX = 442; //EEPROM Adr = 23

int minL2 = 465;  //EEPROM Adr = 25
int maxL2 = 750;  //EEPROM Adr = 27
int minR2 = 670;  //EEPROM Adr = 29
int maxR2 = 1023; //EEPROM Adr = 31

//Joystick LookUp Tables, compiled at startup or after joystick calibration.
byte leftXLUT[1024];
byte leftYLUT[1024];
byte rightXLUT[1024];
byte rightYLUT[1024];

//Joystick Settings
const bool invertLeftY = true;        //------------------------------------------
const bool invertLeftX = false;       //Change these settings for Inverted mounting 
const bool invertRightY = false;      //of joysticks.
const bool invertRightX = false;      //------------------------------------------
const int deadBandLeft = 25;          //
const int deadBandRight = 25;         //Joystick deadband settings. Deadband is the same for both axis on each joystick.
const bool useDeadband = true;        //
int joyDeadZone = 25;                 //Secondary Joystick Deadband. Can't remember why I added this, may be able to replace with deadBandLeft or deadBandRight.
const int earlyLeftX = 30;            //--------------------------------------------------
const int earlyLeftY = 30;            //Distance from end of travel to achieve full axis movement. 
const int earlyRightY = 30;           //This helps square out each axis response to allow full movement speed with direction input.
const int earlyRightX = 30;           //--------------------------------------------------
const int triggerDeadband = 40;       //Trigger Deadband
const int mouseSensitivity = 20;      //Sensitivity Setting for mouse movements
const int mouseRightClick = 40;       //Deadband for mouse right click

//LED Setup
#define NUM_LEDS 6  //Number of LED's
#define DATA_PIN 7  //IO pin of LED's
CRGB leds[NUM_LEDS];  //Setup LED's
int LED_Values[6] = {0,0,0,0,0,0}; //Array to store brightness values of LED's
int ledHue = 150; //LED Hue
int ledSat = 255; //LED Saturation
int ledBrightness = 255; //LED Brightness
int currentBrightness;  //Current LED Brightness
String rgbMode[2] = {"Breath","Halo"}; //LED pattern. Used in RGB Menu
int rgbModeSelect = 0;  //LED mode selected in menu
unsigned long LED_Timer;  //LED effect timer
unsigned long LED_Fadeout;  //LED fade out timer
unsigned long LED_Fadein; //LED fade in timer
int LED_Speed = 20; //LED Effect Speed
int LED_OutSpeed = 20;  //LED fade out speed
int ledSequenceNo = 0;  //Used to store which LED we are up to in the animation sequence

//Controller Button setup
int buttonCount = 7;                   //Number of buttons connected to Pico
byte buttonPins[7] = {0,1,8,13,4,6,9}; //A,B,X,Y,Menu, R1, R3
byte modeSwitch = 5;                   //Digital IO of controller mode switch
int lastMode = 2;                      //Last controller mode displayed. Used for display updates. 0 = Controller Mode, 1 = Keyboard Mode, 2 = Initialised

//Menu Variables
unsigned long interfaceTimer;     //Timer for menu interface
int interfaceDelay = 120;         //frequency to check for button presses in menu operation
bool menuOpen = false;            //Set to true to open Main menu
bool rgbMenu = false;             //Set to true to open RGB menu
bool batteryMenu = false;         //Set to true to open Battery menu
boolean calibrationMode = false;  //Set to true to open Calibration menu
int menuSelected = 0;             //which menu item is highlighted
int menuOptions = 7;              //Number of Items in Menu List
String mainMenu[7] = {"Aim Assist","Calibrate", "Battery", "RGB", "Settings", "ALT F4", "ESC"}; //Main Menu titles
bool aimAssist = true;            //If aim assist is enabled. NOT YET IMPLEMENTED
bool shutdownMode = false;        //Set to true if shutdown is initiated
int calibrationStep = 1;          //Stage of calibration process
bool calibrationDisplayUpdate = false;  //Used for display updates during calibration process        

//Button state arrays
byte lastButtonState[17]; //Empty State array for buttons last sent state.
byte currentButtonState[17]; //Empty State array for buttons.

TFT_eSPI tft = TFT_eSPI();  //Setup controller display.
/*The rest of display settings are configured in User_Setup.h from the TFT_eSPI library. Your display will not function until this file is set up
correctly. The following settings are what is required:

#define USER_SETUP_INFO "User_Setup"
#define ST7735_DRIVER
#define TFT_RGB_ORDER TFT_BGR
#define TFT_WIDTH  80
#define TFT_HEIGHT 160
#define ST7735_GREENTAB160x80
#define TFT_INVERSION_ON
#define TFT_CS   10
#define TFT_DC   16
#define TFT_RST  17
#define TFT_MOSI 19
#define TFT_SCLK 18
#define LOAD_GLCD
#define LOAD_FONT2
#define SMOOTH_FONT
#define SPI_FREQUENCY  27000000
#define SPI_READ_FREQUENCY  20000000
#define SPI_TOUCH_FREQUENCY  2500000
*/

//Battery
int batteryPercent = 100;           //System state of charge. Used to for battery display
bool charging = false;              //Set to true when charger is detected and battery is < 99.95%
bool lastChargingDisplay = false;   //Used for display update of charging status
bool onAC = false;                  //Set to true when charger is detected and battery is > 99.95%
long lastBatteryUpdate = 0;         //Battery display timer
int batteryUpdateInterval = 5000;   //Battery display update interval
String TTE;                         //String for storing time till empty. Used in battery display
float lastSOC;                      //SOC when last checked. Used for display update.
float currentSOC;                   //Current State of charge.
int lastBatteryDisplay;             //Last battery percentage displayed. Used for display update.

void setup() {
  //Left Controller I2C Setup
  Wire.setSDA(CONTROLLER_I2C_SDA);
  Wire.setSCL(CONTROLLER_I2C_SCL);
  Wire.begin();

  //MPU6050 Setup
  Wire1.setSDA(MPU6050_SDA);
  Wire1.setSCL(MPU6050_SCL);
  Wire1.begin();
  mpu6050_Setup();

  //Controller Output Setup
  Joystick.begin();
  Joystick.useManualSend(true);
  Joystick.use8bit(true);

  //Mouse and Keyboard Output Setup
  Mouse.begin();
  Keyboard.begin(KeyboardLayout_en_US);

  //Initialize eeprom
  EEPROM.begin(512);

  //LCD Setup
  tft.init();
  tft.fillScreen(TFT_BLACK);
  
  //LED Setup
  FastLED.addLeds<WS2812, DATA_PIN, RGB>(leds, NUM_LEDS).setCorrection(TypicalLEDStrip);
  FastLED.setBrightness(255);

  //Pico Buttons Setup
  for(int i = 0; i < buttonCount; i++){ //Set all button pins as input pullup. Change to INPUT if using external resistors.
    pinMode(buttonPins[i], INPUT_PULLUP);
  }
  pinMode(modeSwitch, INPUT_PULLUP);  //Turn on pullup for mode switch
  pinMode(28, INPUT); //Set input for right trigger
  pinMode(27, INPUT); //Set input for right joystick X
  pinMode(26, INPUT); //Set input for right joystick Y

  //PC Power Switch
  pinMode(3, OUTPUT); //Setup power switch pin as an output
  digitalWrite(3, LOW);  //Set output low so power doesn't switch off immediately 

  Serial.begin(9600); //Begin serial connection. Uncomment following two lines for debugging to ensure serial has connected before output begins.
  //while (!Serial)
     //delay(10);
  max17261Init(); //Set up fuel gauge
  calculate_IMU_error();  //Setup MPU6050
  readCalibrationData();  //Read joystick calibration from EEPROM
  rebuildLUTs();          //Build Lookup Tables with data from EEPROM
  startupScreen();        //Display welcome screen
  delay(5000);            //Wait 5s
}

void loop() {
  if(rgbModeSelect == 0){
    rgbBreath();
  } else {
    rgbHalo();
  }
  buttonRead();
  mediaControls();
  if(!menuOpen && !calibrationMode && !rgbMenu && !batteryMenu){
    mainScreen();
    if(lastButtonState[4] == 1){
      menuMode();
    }
    if(lastMode == 0){
      gamepadMode();
    } else {
      keyboardMode();
    }
    modeToggle();
  }
  if(menuOpen){
    menuMode();
  }
  if(calibrationMode){
    joystickCalibration();
  }
  if(rgbMenu){
    rgbConfig();
  }
  if(batteryMenu){
    batteryInfo();
  }
  currentSOC = getSOC();
  batteryPercent = currentSOC;

  if(lastSOC < currentSOC){
    charging = true;
    lastSOC = currentSOC;
  }
  if(lastSOC > currentSOC){
    charging = false;
    lastSOC = currentSOC;
  }
  if(currentSOC > 99.95){
    onAC = true;
  }

  if(lastBatteryUpdate + batteryUpdateInterval < millis() | lastBatteryUpdate == 0){
    float timeToEmpty = getTimeToEmpty();
    int hours = timeToEmpty;
    int minutes = ((timeToEmpty - hours) * 60);
    if(minutes < 10){
      TTE = ((String)hours + ":0" + (String)minutes);
    } else {
      TTE = ((String)hours + ":" + (String)minutes);
    }
    lastBatteryUpdate = millis();
  }
}

void rebuildLUTs(){ //Rebuild all joystick LUT's at once.
  joystickBuildLUT(leftXLUT, minLeftX, midLeftX, maxLeftX, earlyLeftX, deadBandLeft, invertLeftX);
  joystickBuildLUT(leftYLUT, minLeftY, midLeftY, maxLeftY, earlyLeftY, deadBandLeft, invertLeftY);
  joystickBuildLUT(rightXLUT, minRightX, midRightX, maxRightX, earlyRightX, deadBandRight, invertRightX);
  joystickBuildLUT(rightYLUT, minRightY, midRightY, maxRightY, earlyRightY, deadBandRight, invertRightY);
}

 /*This function builds a lookup table for the given axis using the provided min, max and middle values for each axis. Early stop, deadband and inversion 
  * are all configurable via the joystick settings variables. Maximum, minimum and mid point are all set by the calibration sequence.
  */
void joystickBuildLUT(byte output[1024], int minIn, int midIn, int maxIn, int earlyStop, int deadBand, bool invert){
  unsigned int temp;
  
  for(int i = 0; i < 1024; i++){
    if(i < midIn){
      if(i > minIn + earlyStop){
        temp = map(i, minIn, midIn - deadBand, 0, 127);
      } else {
        temp = 0;
      }
    } else {
      if(i < maxIn - earlyStop){
        temp = map(i, midIn + deadBand, maxIn, 127, 254);
      } else {
        temp = 254;
      }
    }
    if(i < midIn + deadBand && i > midIn - deadBand){
      temp = 127;
    }
    if(invert){
      temp = map(temp, 0, 254, 254, 0);
    }
    output[i] = temp;
  }
}

void buttonRead(){ //Read button inputs and set state arrays.
  for (int i = 0; i < buttonCount; i++){
    int input = !digitalRead(buttonPins[i]);
    if (input != lastButtonState[i]){
      lastButtonState[i] = input;
    }
  }
  unsigned int buttonReq = i2c_Request(controllerAddr, buttons);
  //Serial.println(buttonReq);
  for (int i = 0; i < i2cButtonCount; i++){
    if(buttonReq & 0b00000001 == 1){
      lastButtonState[i+buttonCount] = 1; //Pressed
    } else {
      lastButtonState[i+buttonCount] = 0; //Un-Pressed
    }
    buttonReq = buttonReq >> 1;
  }
}

/*int joystickScale(int val, int min, int max, int mid, bool invert){
  if(!invert){
    if(val < (mid - joyDeadZone) || val > (mid + joyDeadZone)){
      val = map(val, min - 10, max + 10, -32767, 32767);
    } else {
      val = 0;
    }
  } else {
    if(val < (mid - joyDeadZone) || val > (mid + joyDeadZone)){
      val = map(val, min - 10, max + 10, 32767, -32767);
    } else {
      val = 0;
    }
  }
  return val;
}*/

void gamepadMode(){ //Controller Gamepad mode
  joystickInput();
  //Buttons
  for(int i = 0; i < buttonCount + i2cButtonCount; i++){
    if(lastButtonState[i] != currentButtonState[i]){
      Joystick.button(i + 1, lastButtonState[i]);
      currentButtonState[i] = lastButtonState[i];
    }
  }
  Joystick.send_now();
  //delay(1);
}

void zeroGamepad(){ //Called to Zero all gamepad outputs when switching to keyboard mode
  for(int i = 0; i < buttonCount + i2cButtonCount; i++){
    Joystick.button(i + 1, 0);
  }
  Joystick.sliderLeft(127);
  Joystick.sliderRight(127);
  Joystick.Y(127);
  Joystick.X(127);
  Joystick.Z(0);
  Joystick.Zrotate(0);
  Joystick.send_now();
  //delay(1);
}

int i2c_Request(int adr, int i2c_Reg){ //Controller i2c request
  Wire.beginTransmission(adr);
  Wire.write(i2c_Reg);
  Wire.endTransmission();
  Wire.requestFrom(adr, 2);
  while (Wire.available()) {
    int readingLow = Wire.read();
    int readingHigh = Wire.read();
    return(word(readingHigh, readingLow));
  }
  return 0;
}

void mediaControls(){ //Volume button controls
  if(lastButtonState[7] == 1){
    Keyboard.consumerPress(KEY_VOLUME_INCREMENT);
    delay(50);
  } else if(lastButtonState[8] == 1){
    Keyboard.consumerPress(KEY_VOLUME_DECREMENT);
    delay(50);
  } else {
    if(!shutdownMode){
      Keyboard.consumerRelease();
    }
  }
}

void keyboardMode(){  //Controller Keyboard/mouse mode
  //Set all gamepad buttons/axis to 0.
  zeroGamepad();
  //Left Click
  if(lastButtonState[5] == 1){
    Mouse.press(MOUSE_LEFT);
  } else {
    Mouse.release(MOUSE_LEFT);
  }
  //Right Click
  if(triggerScale(analogRead(28), minR2, maxR2) > mouseRightClick){
    Mouse.press(MOUSE_RIGHT);
  } else {
    Mouse.release(MOUSE_RIGHT);
  }
  
  
  int mouseMoveX;
  int mouseMoveY;
  int var = i2c_Request(controllerAddr, xAxis);

  if(var != 0){
    mouseMoveX = map((leftXLUT[var]), 0, 254, -mouseSensitivity, mouseSensitivity);
  } else {
    mouseMoveX = 0;
  }
  var = i2c_Request(controllerAddr, yAxis);
  if(var != 0){
    mouseMoveY = map((leftYLUT[var]), 0, 254, -mouseSensitivity, mouseSensitivity);
  } else {
    mouseMoveY = 0;
  }

  Mouse.move(mouseMoveX,mouseMoveY);  //Moves mouse relative position. X,Y

  if(lastButtonState[11] == 1){
    Keyboard.press(KEY_ESC);  //Escape
    delay(50);
  } else if(lastButtonState[0] == 1){ 
    Keyboard.press(KEY_RETURN);  //Enter
    delay(50);
  } else if(lastButtonState[16] == 1){
    Keyboard.press(KEY_UP_ARROW);
    delay(50);
  } else if(lastButtonState[15] == 1){
    Keyboard.press(KEY_DOWN_ARROW);
    delay(50);
  } else if(lastButtonState[14] == 1){
    Keyboard.press(KEY_LEFT_ARROW);
    delay(50);
  } else if(lastButtonState[13] == 1){
    Keyboard.press(KEY_RIGHT_ARROW);
    delay(50);
  } else {
    Keyboard.releaseAll();
  }
}

void modeToggle(){  //Update display for controller mode
  int mode = digitalRead(modeSwitch);
  if(mode != lastMode){
    tft.fillScreen(TFT_BLACK);
    lastBatteryDisplay = 0;
    tft.setTextSize(1);
    if(mode){   
      tft.drawString("Keyboard", 11, 130, 2);
      tft.drawString("Mode", 25, 145, 2);
      tft.drawXBitmap(18, 100, keyboardIMG, keyboardWidth, keyboardHeight, TFT_WHITE);
    } else {
      tft.drawString("Controller", 10, 130, 2);
      tft.drawString("Mode", 25, 145, 2);
      tft.drawXBitmap(18, 100, gamepadIMG, gamepadWidth, gamepadHeight, TFT_WHITE);
    }
    lastMode = mode;
  }
}

void eepromLoad(){ //Loads stored settings from EEPROM
  if(readIntFromEEPROM(1) != -1){ //Check Joystick Calibration in EEPROM is not Empty
    readCalibrationData(); //Load joystick calibration from EEPROM
  }
}

void writeIntIntoEEPROM(int address, int number){ //Splits Int into BYTES for EEPROM
  byte byte1 = number >> 8;
  byte byte2 = number & 0xFF;
  EEPROM.write(address, byte1);
  EEPROM.write(address + 1, byte2);
}

int readIntFromEEPROM(int address){ //Converts BYTES to INT from EEPROM
  byte byte1 = EEPROM.read(address);
  byte byte2 = EEPROM.read(address + 1);
  return (byte1 << 8) + byte2;
}

void readCalibrationData(){ //Read calibration data from EEPROM
//Left X
  minLeftX = readIntFromEEPROM(1);
  maxLeftX = readIntFromEEPROM(3);
  midLeftX = readIntFromEEPROM(5);
//Left Y
  minLeftY = readIntFromEEPROM(7);
  maxLeftY = readIntFromEEPROM(9);
  midLeftY = readIntFromEEPROM(11);
//Right Y
  minRightY = readIntFromEEPROM(13);
  maxRightY = readIntFromEEPROM(15);
  midRightY = readIntFromEEPROM(17);
// Right X
  minRightX = readIntFromEEPROM(19);
  maxRightX = readIntFromEEPROM(21);
  midRightX = readIntFromEEPROM(23);
// L2
  minL2 = readIntFromEEPROM(25);
  maxL2 = readIntFromEEPROM(27);
// R2
  minR2 = readIntFromEEPROM(29);
  maxR2 = readIntFromEEPROM(31);
}

void writeCalibrationData(){ //Store calibration data in EEPROM
//Left X
  writeIntIntoEEPROM(1, minLeftX);
  writeIntIntoEEPROM(3, maxLeftX);
  writeIntIntoEEPROM(5, midLeftX);
//Left Y
  writeIntIntoEEPROM(7, minLeftY);
  writeIntIntoEEPROM(9, maxLeftY);
  writeIntIntoEEPROM(11, midLeftY);
//Right Y
  writeIntIntoEEPROM(13, minRightY);
  writeIntIntoEEPROM(15, maxRightY);
  writeIntIntoEEPROM(17, midRightY);
// Right X
  writeIntIntoEEPROM(19, minRightX);
  writeIntIntoEEPROM(21, maxRightX);
  writeIntIntoEEPROM(23, midRightX);
// L2
  writeIntIntoEEPROM(25, minL2);
  writeIntIntoEEPROM(27, maxL2);
// R2
  writeIntIntoEEPROM(29, minR2);
  writeIntIntoEEPROM(31, maxR2);
//Commit Changes
  EEPROM.commit();
}

void joystickInput(){ //Read joysticks and compare to LUT's . Read triggers and scale output
  int var = analogRead(26);
  if(aimAssist){
    Joystick.sliderLeft((rightYLUT[var] + yOffset) -127);
  } else {
    Joystick.sliderLeft((rightYLUT[var]) -127);
  }
  
  var = analogRead(27);
  if(aimAssist){
    Joystick.sliderRight((rightXLUT[var] + xOffset) -127);
  } else {
    Joystick.sliderRight((rightXLUT[var]) -127);
  }
  
  
  var = i2c_Request(controllerAddr, yAxis);
  if(var != 0){
    Joystick.Y((leftYLUT[var]) -127);
  }
  
  var = i2c_Request(controllerAddr, xAxis);
  if(var != 0){
    Joystick.X((leftXLUT[var]) -127);
  }

  var = i2c_Request(controllerAddr, zAxis);
  if(var != 0){
    var = triggerScale(var, minL2, maxL2);
    Joystick.Z(var -127);
  }

  var = analogRead(28);
  var = triggerScale(var, minR2, maxR2);
  Joystick.Zrotate(var -127);
}

int triggerScale(int value, int min, int max){  //Trigger scaling
  if(value < min + triggerDeadband){
    value = min;
  }
  if(value > max){
    value = max;
  }
  
  return map(value, min, max, 0, 254);
}

void read_MPU6050(){  //Read data from MPU6050. Incomplete. Motion control not yet implemented
  if(gyroTimer + 20 < millis()){
    if(yOffset > 0){
      yOffset--;
    }
    if(yOffset < 0){
      yOffset++;
    }
    if(xOffset > 0){
      xOffset--;
    }
    if(xOffset < 0){
      xOffset++;
    }
    gyroTimer = millis();
  }
  Wire1.beginTransmission(MPU6050);
  Wire1.write(0x43); // Gyro data first register address 0x43
  Wire1.endTransmission(false);
  Wire1.requestFrom(MPU6050, 6, true); // Read 4 registers total, each axis value is stored in 2 registers
  GyroX = (Wire1.read() << 8 | Wire1.read()) / 131.0; // For a 250deg/s range we have to divide first the raw value by 131.0, according to the datasheet
  GyroY = (Wire1.read() << 8 | Wire1.read()) / 131.0;
  GyroZ = (Wire1.read() << 8 | Wire1.read()) / 131.0;
  // Correct the outputs with the calculated error values
  GyroX = GyroX + 0.56; // GyroErrorX ~(-0.56)
  GyroY = GyroY - 2; // GyroErrorY ~(2)
  GyroZ = GyroZ + 0.79; // GyroErrorZ ~ (-0.8)

  int var = GyroX - GyroLastX;
  
  if(var > 2 || var < -2){ //deadzone
    if(var < 20 && var > -20){
      yOffset = var;
    }
    if(var > 20){
      yOffset = 20;
    }
    if(var < -20){
      yOffset = -20;
    }
  }
  GyroLastX = GyroX;

  var = GyroY - GyroLastY;
  //xOffset = 0;
  if(var > 2 || var < -2){ //deadzone
    if(var < 20 && var > -20){
      xOffset = var;
    }
    if(var > 20){
      xOffset = 20;
    }
    if(var < -20){
      xOffset = -20;
    }
  }
  GyroLastY = GyroY;

}

void mpu6050_Setup(){
  Wire1.begin();                      // Initialize comunication
  Wire1.beginTransmission(MPU6050);       // Start communication with MPU6050 // MPU=0x68
  Wire1.write(0x6B);                  // Talk to the register 6B
  Wire1.write(0x00);                  // Make reset - place a 0 into the 6B register
  Wire1.endTransmission(true);
}
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

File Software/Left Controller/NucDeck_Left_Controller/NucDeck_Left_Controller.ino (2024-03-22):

#include <Wire.h>

byte i2cAddr = 0x01;    //Left Controller i2c address
byte buttons = 0xF1;    //Register for buttons
byte xAxis = 0xF2;      //Register for xAxis
byte yAxis = 0xF3;      //Register for yAxis
byte zAxis = 0xF4;      //Register for zAxis
byte outputMode = 0x00; //Set to match a register for output
byte outputArray[2];    //Output data stored here

//Buttons
byte buttonPins[10] = {0,1,2,3,4,5,6,7,8,9}; //Up, Down, Left, Right, Start, Select, L1, L3, Vol+, Vol-
byte buttonCount = 10;
byte lastButtonState[10]; //Button state storage

//Analog Axis
byte xAxisPin = A0;
byte yAxisPin = A1;
byte zAxisPin = A2;
int xAxisValue;
int yAxisValue;
int zAxisValue;

void setup() {
  Wire.begin(i2cAddr);          //Begin i2c communication
  Wire.onRequest(requestEvent); //Call requestEvent() function when a request is received.
  Wire.onReceive(receiveEvent); //Call rreceiveEvent() function when a data is received.

  for(int i = 0; i < buttonCount; i++){ //Setup controller input pins
    pinMode(buttonPins[i], INPUT_PULLUP);
  }
  pinMode(xAxisPin, INPUT);
  pinMode(yAxisPin, INPUT);
  pinMode(zAxisPin, INPUT);
}

void loop() {
  buttonRead();
  axisRead();
}

void buttonRead(){ //Read button inputs and set state arrays.
  for (int i = 0; i < buttonCount; i++){ 
    int input = !digitalRead(buttonPins[i]);
    if (input != lastButtonState[i]){
      lastButtonState[i] = input;
    }
  }
}

void axisRead(){  //Read analog axis and store values
  xAxisValue = analogRead(xAxisPin);
  yAxisValue = analogRead(yAxisPin);
  zAxisValue = analogRead(zAxisPin);
}

void buttonOutput(){  //Package current state of buttons into output array as bytes. Each byte of the output represents a button.
  unsigned int output = 0;
  for(int i = 0; i < buttonCount; i++){
    output = output << 1;
    if(lastButtonState[i] == 1){
      output += 1;
    }
  }
  outputArray[0] = lowByte(output);
  outputArray[1] = highByte(output);
}

void requestEvent(){ //Send the requested data
  if(outputMode == buttons){
    buttonOutput();
    Wire.write(outputArray,2);
  } else if(outputMode == xAxis){
    outputArray[0] = lowByte(xAxisValue);
    outputArray[1] = highByte(xAxisValue);
    Wire.write(outputArray,2);
  } else if(outputMode == yAxis){
    outputArray[0] = lowByte(yAxisValue);
    outputArray[1] = highByte(yAxisValue);
    Wire.write(outputArray,2);
  } else if(outputMode == zAxis){
    outputArray[0] = lowByte(zAxisValue);
    outputArray[1] = highByte(zAxisValue);
    Wire.write(outputArray,2);
  }
}

void receiveEvent(int value){ //Sets which output type is being requested
  while(Wire.available()){
    outputMode = Wire.read();
  }
}

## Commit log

2023-07-30 Move Files to folder
    [7gi5 Back Cover.STEP, Housing Front.STEP, Joystick Surround Ring.STEP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]
2023-07-30 Add STLs
    [Action Button A.STL, Action Button B.STL, Action Button X.STL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]
2023-07-30 Parts list updated
    [Controller Mode Toggle.STL]
2023-07-30 Updated Different Versions of buttons
    [7gi5 Back Cover.STEP, Action Button A.STL, Action Button B.STL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]
2023-08-07 Updated files
    [+ Volume Button.STEP, + Volume Button.STL, - Volume Button.STEP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]
2023-08-11 Upload Test Print
    [TouchScreen Scale Test.STL]
2023-09-18 Added STL for joystick surround rings
    [Joystick Surround Ring.STL]
2023-09-18 Added trigger buttons
    [Trigger Button Left.STEP, Trigger Button Left.STL, Trigger Button Right.STEP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]
2024-01-07 Controller PCB's
    [NucDeck Left Controller PCB.csv, NucDeck Left Controller PCB.kicad_pcb, NucDeck Left Controller PCB.kicad_sch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]
2024-03-22 Added BMS and Controller Software
    [NucDeck Desktop Stand.STL, NucDeck Left Top Controller BMS PCB - Rev 1.1.csv, NucDeck Left Top Controller BMS PCB - Rev 1.1.kicad_pcb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]
2024-04-12 Update NucDeck Left Top Controller BMS PCB - Rev 1.1.csv
    Update inductor part number
    [NucDeck Left Top Controller BMS PCB - Rev 1.1.csv]
2024-04-12 Update NucDeck Left Top Controller BMS PCB - Rev 1.1.csv
    Update Sense Resistor Part Number
    [NucDeck Left Top Controller BMS PCB - Rev 1.1.csv]
2024-04-13 Update README.md
    Added cost to build
    Added battery cell balancer to list
2024-07-31 Update README.md
    Updated lipo cell balancer link
